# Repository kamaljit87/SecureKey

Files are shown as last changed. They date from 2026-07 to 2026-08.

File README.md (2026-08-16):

<div align="center">

# 🔐 SecureKey

### An offline, hardware password manager that **types your passwords for you** — over USB‑C *and* Bluetooth.

Built on a 1.8" AMOLED touchscreen ESP32‑S3. No cloud. No app account. Your vault never leaves the device.









</div>

> **SecureKey** is a DIY [hardware password manager](https://en.wikipedia.org/wiki/Password_manager) — a tiny touchscreen "keyboard emulator." Pick an entry, tap a field, and the device types it into whatever it's plugged into (PC over USB‑C) or paired with (phone/laptop over Bluetooth). Because it presents itself as a **HID keyboard**, it works on any OS with zero drivers, zero browser extensions, and zero software installed. The secrets live in flash on the device, behind a PIN — never synced, never uploaded.

<p align="center">
  SecureKey on-device screens — Lock, Home, and password Detail
  <br><sub><i>Illustrative renders of the on‑device UI · 368 × 448 AMOLED</i></sub>
</p>

---

## 🔑 What it does, in one picture

```mermaid
flowchart LR
    V["Your vault<br/>lives on the device"] --> P["Pick an entry,<br/>tap a field"]
    P --> Q{"Connected<br/>how?"}
    Q -->|USB-C cable| U["Types into your<br/>PC / Mac as a keyboard"]
    Q -->|Bluetooth| W["Types into your phone<br/>or laptop, wirelessly"]
```

To the computer it just looks like someone typing — **no app, no browser extension, no account.**

---

## 🆚 How it compares

| | **SecureKey** | Cloud manager | Browser autofill |
|---|:---:|:---:|:---:|
| Where the secrets live | 🔒 on the device | ☁️ a company server | 💻 your browser profile |
| Needs an account | ❌ | ✅ | ✅ |
| Needs software on the host | ❌ | ✅ | ✅ |
| Works on any device, no install | ✅ | ❌ | ❌ |
| Usable fully offline | ✅ | ❌ | ❌ |
| Open hardware + firmware | ✅ | ❌ | ❌ |

---

## ✨ Features

| | Feature | What it does |
|---|---|---|
| ⌨️ | **Dual‑transport typing** | Types passwords as real keystrokes over **USB‑C HID** *and* **Bluetooth LE HID** — both can be live at once. |
| 🔢 | **PIN lock + brute‑force backoff** | 4‑digit unlock with escalating lockout (30 s → 60 s → 2 m → 5 m) that survives reboots. |
| 📶 | **On‑device BLE pairing gate** | A connecting phone is *blocked* until you tap **Accept** on the device. Reject, or **Block for 5 min**. Shows the peer's Bluetooth address. |
| 🗂️ | **30,000‑entry vault** | Fixed‑size binary records on FFat, with a PSRAM index so the list scrolls instantly. |
| 🔎 | **Instant search & favorites** | Live filtering with an on‑screen keyboard, plus a ❤️ favorites view. |
| 🌐 | **Wi‑Fi import/export portal** | Spin up a captive‑portal web app to bulk‑import a CSV (Chrome/Google export auto‑detected) or export your vault — code‑protected. |
| ✋ | **Drag‑to‑rearrange home** | Long‑press a home tile and drag it, just like arranging apps on a phone. Order persists. |
| 🅰️ | **Android `@` fix** | One‑tap toggle that fixes the classic US↔UK keycode swap (where `@` types as `"`) on Android hosts. |
| 🔒 | **Auto‑lock, sleep, factory reset** | Idle auto‑lock, double‑tap‑to‑sleep, PIN‑gated factory wipe, change‑PIN flow. |
| 🎨 | **Hand‑drawn AMOLED UI** | A custom, double‑buffered graphics UI (no LVGL) tuned for pure‑black AMOLED — glow effects, color avatars, pill toggles. |

---

## 🧭 Getting around

```mermaid
flowchart LR
    L["Lock"] --> P["PIN"]
    P --> H["Home"]
    H --> List["Passwords"]
    H --> Add["Add new"]
    H --> Fav["Favorites"]
    H --> Set["Settings"]
    List --> D["Detail<br/>tap a field → it types"]
```

> The renders at the top show the Lock, Home, and Detail screens. Real device photos are welcome — drop them in `docs/img/` and link them here.

---

## 🧰 Hardware

| Part | Detail |
|---|---|
| **Board** | [MaTouch ESP32‑S3 1.8" AMOLED (FT3168)](https://www.makerfabs.com/) — ESP32‑S3 R8 |
| **MCU** | ESP32‑S3, dual‑core, **8 MB OPI PSRAM**, **16 MB flash** |
| **Display** | 1.8" AMOLED, **368 × 448**, SH8601 controller over **QSPI** |
| **Touch** | FT3168 capacitive, I²C |
| **LED** | WS2812 (single RGB pixel) — status feedback |
| **USB** | USB‑C, native ESP32‑S3 (USB‑OTG / TinyUSB) |
| **Power** | USB‑C, optional 3.7 V LiPo |

---

## 🚀 Quick start

### 1. Install the toolchain (use these **exact** versions)

| Tool | Version | Where |
|---|---|---|
| Arduino IDE | 2.3.x | [arduino.cc](https://www.arduino.cc/en/software) |
| `esp32` boards core | **2.0.16** | Boards Manager — do **not** use 3.x |
| GFX Library for Arduino | **1.3.7** | Library Manager |
| NimBLE‑Arduino | **1.4.3** | Library Manager — do **not** use 2.x |
| ESP32 BLE Keyboard (T‑vK) | latest | Library Manager *(+ 2 small patches, below)* |
| Adafruit NeoPixel | latest | Library Manager |

Add this Boards Manager URL first (**File → Preferences → Additional URLs**):
```
https://raw.githubusercontent.com/espressif/arduino-esp32/gh-pages/package_esp32_index.json
```

### 2. Patch the BLE keyboard library (two one‑line edits)

The stock **ESP32 BLE Keyboard** ships with the heavyweight Bluedroid backend and MITM‑required pairing, which break USB+BLE coexistence and silent‑fail on Windows/Android. In your `…/Arduino/libraries/ESP32_BLE_Keyboard/` copy:

```diff
// BleKeyboard.h
- // #define USE_NIMBLE
+ #define USE_NIMBLE          // half the RAM; coexists with native USB HID

// BleKeyboard.cpp  (inside begin(), the USE_NIMBLE branch)
- BLEDevice::setSecurityAuth(true, true, true);
+ BLEDevice::setSecurityAuth(true, false, true);   // SC "Just Works" pairing
```

### 3. Arduino IDE board settings (Tools menu)

```
Board:              ESP32S3 Dev Module
PSRAM:              OPI PSRAM                       ← REQUIRED (canvas lives here)
Flash Size:         16MB (128Mb)
Partition Scheme:   16M Flash (3MB APP/9.9MB FATFS)
USB CDC On Boot:    Enabled
USB Mode:           USB-OTG (TinyUSB)               ← REQUIRED for USB HID typing
Upload Mode:        UART0 / Hardware CDC
CPU Frequency:      240MHz
Flash Mode:         QIO 80MHz
```

### 4. Flash

Open `06_PasswordManager/06_PasswordManager.ino` and Upload. First boot seeds a few demo entries so you can see the UI immediately.

<details>
<summary><b>Prefer the command line? (arduino-cli)</b></summary>

```bash
arduino-cli compile \
  --fqbn "esp32:esp32:esp32s3:PartitionScheme=app3M_fat9M_16MB,PSRAM=opi,FlashSize=16M,USBMode=default,CDCOnBoot=cdc" \
  06_PasswordManager
```
(`USBMode=default` is USB‑OTG/TinyUSB.) This is exactly what the [CI workflow](.github/workflows/build.yml) runs on every push.
</details>

### 5. First unlock

There's no default PIN. First boot walks you through choosing your own PIN
(4/6/8 digits — 6+ recommended), which is used to derive the key that
protects your vault and is never itself stored on the device. See
[docs/SECURITY.md](docs/SECURITY.md) for how this works.

---

## 🕹️ Using it

1. **Tap to wake → enter PIN → Home.**
2. Open **Passwords**, tap an entry.
3. On the detail screen, **tap any field** (Title / User / Pass / URL / Note) — SecureKey **types it** into the focused field on your computer/phone.
4. Password is masked; first tap reveals it, second tap types it.
5. **Bottom bar:** `EDIT` · ❤️ · `DELETE`.

**To type over USB:** plug the USB‑C into a PC data port → tap a field. **To type over Bluetooth:** Settings → turn on Bluetooth → pair "SecureKey" from your phone → unlock the device → tap **Accept** on the request → tap a field.

> 💡 If `@` comes out as `"` on Android, enable **Settings → Android @ Fix**.

---

## 🧠 Feature concepts (how it actually works)

A short tour of the interesting engineering. For the full deep dive see **[docs/ARCHITECTURE.md](docs/ARCHITECTURE.md)**.

### ⌨️ HID — "the device *is* a keyboard"
Both USB and Bluetooth expose a standard **[HID keyboard](https://en.wikipedia.org/wiki/USB_human_interface_device_class)**. The OS sees a normal keyboard, so typing works everywhere with no software. The firmware sends **scancodes**, and the host applies its own keyboard layout — which is why the Android `@`→`"` swap exists (see below).

### 🔀 Dual transport on a dual‑core chip
USB HID uses **TinyUSB**; Bluetooth HID uses **NimBLE** (chosen over Bluedroid because it uses ~half the RAM and coexists with native USB). The ESP32‑S3 has two cores and NimBLE runs its own radio task, so **both transports can be live simultaneously** — `typeViaHID()` sends to *every* ready transport instead of picking one.

### 📶 The Bluetooth pairing gate
A BLE *central* (your phone) can connect to the device any time, but SecureKey **types nothing until you physically accept it** on‑screen — and the prompt only appears *after* you've entered your PIN. You can **Accept**, **Reject** (snoozes the prompt so an auto‑reconnecting phone doesn't nag), or **Block 5 min** (drops the radio). The prompt shows the peer's Bluetooth MAC. *(A BLE central doesn't transmit a friendly name to a keyboard, so the address is what's identifiable.)*

```mermaid
sequenceDiagram
    participant Phone
    participant SecureKey
    participant You
    Phone->>SecureKey: BLE connect
    Note over SecureKey: typing stays BLOCKED
    SecureKey->>You: "A device wants to connect" (after PIN unlock)
    You-->>SecureKey: Accept / Reject / Block 5 min
    Note over SecureKey: only Accept unlocks typing
    SecureKey->>Phone: now types your password
```

### 🔑 The Android `@`→`"` fix
HID sends key *positions*, not characters. On a host set to a UK/Android layout, `Shift+2` is `"` (not `@`), and `@` lives on `Shift+'`. The **Android @ Fix** toggle swaps those two keycodes on the BLE path so symbols land correctly — the classic US↔UK keyboard difference, solved in firmware.

### 🗂️ Storage: flat binary + PSRAM index
The vault is **fixed‑size 256‑byte records** appended to a single FFat file (`db.bin`). At boot a compact 64‑byte **index** per entry is loaded into **PSRAM**, so searching, sorting, and scrolling never touch flash. Deletes are tombstoned; edits rewrite in place. This scales to **30,000 entries** (≈1.9 MB index in PSRAM, ≈7.3 MB on the 9 MB FAT partition).

### 🛡️ PIN lockout backoff
Wrong PINs trigger an **escalating, persisted** lockout (30 s → 60 s → 2 m → 5 m). The fail count lives in NVS, so power‑cycling doesn't reset the penalty — a brute‑force attacker can't just yank power to retry instantly.

### 🌐 Wi‑Fi import/export portal
Bulk data entry on a touchscreen is painful, so Settings can launch a **SoftAP + captive‑portal web app**. You join its Wi‑Fi, open the page, enter a one‑time code, and paste a CSV (Chrome/Google password exports auto‑detected) or export your vault. Every entry requires title + username + password — enforced both in the browser and server‑side.

### ✋ Drag‑to‑rearrange home (touch state machine)
The FT3168 driver feeds a tap/drag/swipe state machine. A **long‑press** on a home tile lifts it; it follows your finger; on release it drops into the nearest slot and the others shuffle to make room. The arrangement is saved to NVS and validated as a permutation on load.

### 🎨 Rendering on pure‑black AMOLED
The UI is hand‑drawn into a **double‑buffered canvas** in PSRAM and flushed over QSPI — no LVGL, no flicker. Because AMOLED black is truly off, the theme leans into **glow halos** (banded radial gradients), color **letter‑avatars**, and a blue/red accent system on black.

---

## 🗺️ Architecture

```
06_PasswordManager/
├── 06_PasswordManager.ino   Main: setup/loop, nav stack, HID dispatch, BLE gate, auto-lock
├── theme.h                  Palette, layout constants, PassRecord + ListItem structs, capacity
├── pin_config.h             Board pin map (display, touch, LED, USB)
│
├── hid_usb.cpp              USB-HID keyboard (TinyUSB)            ← isolated translation unit
├── hid_ble.cpp              BLE-HID keyboard (NimBLE) + @ fix     ← isolated translation unit
│
├── storage.ino             FFat binary DB: append/load/delete/update/seed
├── touch_input.ino         FT3168 reader + tap/drag/swipe/long-press state machine
├── gfx_lib.ino             Drawing helpers: text, icons, glow, avatars, status/nav bars
├── keyboard.ino            On-screen keyboard (search + add/edit)
│
├── screen_lock.ino         Branded lock screen
├── screen_pin.ino          4-digit keypad + lockout countdown
├── screen_home.ino         Home grid + drag-to-reorder
├── screen_list.ino         Virtual-scroll list + inline search + favorites
├── screen_detail.ino       Entry detail + Edit/Fav/Delete + tap-to-type
├── screen_add.ino          Multi-step add / edit form
├── screen_settings.ino     Settings, HID test, About, factory reset
├── screen_chgpin.ino       Change-PIN flow
├── screen_wifi.ino         Wi-Fi import status screen
├── wifi_portal.ino         SoftAP + HTTP server (import/export)
└── portal_html.h           The captive-portal single-page web app
```

> ⚠️ **USB & BLE keyboard libraries each `#define KEY_*` macros**, so they cannot share a translation unit. That's why `hid_usb.cpp` and `hid_ble.cpp` are separate `.cpp` files exposing a tiny `extern "C"` surface to the `.ino` code.

---

## 🔐 Security model & honest limitations

Full write‑up (threat model, cryptographic design, migration, and the exact
ESP32‑S3 Flash Encryption / Secure Boot production steps) lives in
**[docs/SECURITY.md](docs/SECURITY.md)**. Summary:

**What it does today**
- Vault is **offline**, PIN‑gated, and **encrypted at rest**: every record is
  AES‑256‑GCM with its own random nonce, under a random 256‑bit master key
  that is itself wrapped by a PBKDF2‑HMAC‑SHA256‑derived key — never the PIN
  directly, and the PIN is never stored anywhere, in any form.
- The screen locks on idle and on the physical button; locking wipes the
  master key from RAM, not just the display.
- Brute‑force PIN backoff persists across reboots, on top of the real KDF
  cost every guess pays regardless of that counter.
- Bluetooth typing requires **explicit on‑device approval** per connection.
- Factory reset destroys the old cryptographic identity entirely (new random
  master key, new salt) — it can't be used to bypass the PIN and recover an
  old vault.
- An existing plaintext vault (pre‑encryption firmware) migrates
  automatically on first boot of this firmware, with a verify‑before‑delete
  step so the old data is never lost to a failed migration.

**What it does *not* do** (see SECURITY.md § Security limitations for the
full list)
- Optional **ESP32‑S3 Flash Encryption + Secure Boot v2** (whole‑flash /
  firmware‑signing hardening on top of the above) is documented but **not
  auto‑enabled** — it's a manual, explicit, one‑way eFuse step you run
  yourself when you're ready for a production device, never something the
  build or firmware does for you.
- A compromised or *currently unlocked* device, sophisticated hardware
  attacks (glitching, side‑channel), and firmware bugs elsewhere in the
  codebase are outside what this (or any) microcontroller password manager
  can fully defend against.

Treat this as a **serious DIY / hobbyist‑grade hardened project**, not a
certified security product — see the roadmap.

---

## 🛣️ Roadmap

- [x] Touch UI, vault, USB + BLE HID, Wi‑Fi import, drag‑reorder
- [x] **AES‑256‑GCM encrypted vault** (random master key, PBKDF2‑derived PIN wrapping — see [docs/SECURITY.md](docs/SECURITY.md))
- [ ] **Flash Encryption + Secure Boot v2 enabled by default in a documented production build** (the steps are written up in SECURITY.md today; still a manual per‑device process, not yet a one‑command flow)
- [ ] **TOTP / 2FA** code generator (HMAC‑SHA1)
- [ ] **FIDO2 / WebAuthn** passkey (ECC P‑256)
- [ ] Custom PCB + 3D‑printed enclosure

---

## 🤝 Contributing

Contributions, bug reports, and hardware ports are welcome — see **[CONTRIBUTING.md](CONTRIBUTING.md)**. The CI compiles the firmware on every push, so make sure your branch builds green.

## 📜 License

[MIT](LICENSE) © Shubh Jaiswal.

## 🙌 Credits

- [Makerfabs](https://www.makerfabs.com/) — MaTouch ESP32‑S3 AMOLED hardware
- [moononournation/Arduino_GFX](https://github.com/moononournation/Arduino_GFX) — display driver
- [h2zero/NimBLE‑Arduino](https://github.com/h2zero/NimBLE-Arduino) — lightweight BLE stack
- [T‑vK/ESP32‑BLE‑Keyboard](https://github.com/T-vK/ESP32-BLE-Keyboard) — BLE HID keyboard
- [adafruit/Adafruit_NeoPixel](https://github.com/adafruit/Adafruit_NeoPixel) — WS2812 LED

<div align="center">

**If this project helped you, drop a ⭐ — it genuinely helps.**

</div>

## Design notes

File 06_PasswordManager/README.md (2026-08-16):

# SecureKey — firmware

This folder is the **SecureKey** password‑manager firmware (Arduino sketch).
Open `06_PasswordManager.ino` in the Arduino IDE and Upload.

👉 Full documentation, build settings, and feature explanations are in the
[**project README**](../README.md) and [**docs/ARCHITECTURE.md**](../docs/ARCHITECTURE.md).

## TL;DR build settings

```
Board:            ESP32S3 Dev Module
PSRAM:            OPI PSRAM
Partition:        16M Flash (3MB APP/9.9MB FATFS)
USB CDC On Boot:  Enabled
USB Mode:         USB-OTG (TinyUSB)
```

Requires: esp32 core **2.0.16**, NimBLE‑Arduino **1.4.3**, GFX Library for Arduino **1.3.7**,
Adafruit NeoPixel, and the patched ESP32 BLE Keyboard (see the project README).

There is no default PIN. First boot walks you through choosing your own PIN
(4/6/8 digits, 6+ recommended) — it's never stored anywhere, only used to
derive the key that unlocks your vault. See
[docs/SECURITY.md](../docs/SECURITY.md) for the full design.

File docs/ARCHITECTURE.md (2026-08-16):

# SecureKey — Architecture & Feature Concepts

A deep dive into how SecureKey works, for contributors and the curious. For the high‑level pitch and setup, see the [README](../README.md).

---

## 1. The big picture

SecureKey is a single‑threaded Arduino sketch built around a **screen state machine** and a **non‑blocking main loop**. There is no RTOS scheduling in user code — instead `loop()` polls touch at ~60 Hz, runs lightweight per‑screen animation timers, and services background managers (BLE, Wi‑Fi portal, auto‑lock). The two HID stacks (USB via TinyUSB, BLE via NimBLE) run their own tasks under the hood.

```
            ┌────────────────────────── loop() @ ~60 Hz ──────────────────────────┐
            │  pollTouch() ─► tap / drag / swipe / long-press  ─►  onTapXxx()      │
            │  per-screen animation ticks (lock pulse, PIN shake, list inertia)    │
            │  BLE manager (advertise state, connect gate)                         │
            │  Wi-Fi captive portal service                                        │
            │  auto-lock / LED auto-clear / physical button                        │
            └──────────────────────────────────────────────────────────────────────┘
```

---

## 2. Screen state machine & navigation

Every screen is a pair of functions:

```c
void drawXxx();                       // render the whole screen into the canvas
void onTapXxx(int16_t x, int16_t y);  // handle a tap at (x, y)
```

`current` holds the active `Screen` enum. A small **navigation stack** (`navStack[10]`, `navTop`) gives Android‑style back behaviour:

- `pushNav(SCR_X)` — go deeper (also runs per‑screen entry hooks, e.g. `buildList()` for the list, `pinSlideIn()` for the PIN animation).
- `popNav()` — go back one level.
- `popToLock()` — collapse to the lock screen (idle timeout, physical button).

`drawAll()` and `dispatchTap()` are the two switch statements that route to the active screen. **Adding a screen = write the pair, add a `SCR_` enum, register in both switches.**

Rendering is **double‑buffered**: everything is drawn into an `Arduino_Canvas` in PSRAM, then `flushScreen()` (`gfx->flush()`) pushes the whole frame to the AMOLED over QSPI in one shot. No partial draws, no flicker, no tearing.

---

## 3. Touch: from capacitive blob to gesture

`touch_input.ino` reads the FT3168 over I²C (`ftReadTouch()` — register `0x02` for the touch count, `0x03` for the first point) and runs a small state machine in `pollTouch()`:

| Transition | Meaning | Fires |
|---|---|---|
| no‑touch → touch | finger down | records start point + time |
| touch → touch (moved > `DRAG_THRESHOLD`) | it's a drag | `onDrag()` live callback |
| touch held > 500 ms, no move | **long‑press** | `homeLongPress()` (home only) |
| touch → release, was a drag | swipe/scroll end | `onSwipeEnd()` |
| touch → release, was short & still | **tap** | `dispatchTap()` |

This single machine powers list scrolling (with inertia/friction), swipe‑back, the slide‑up PIN entrance, and the home drag‑to‑reorder — all without blocking the loop.

---

## 4. Data model & storage

> 🔐 The vault is **encrypted at rest** (AES‑256‑GCM, per‑record nonces, a
> random master key wrapped by a PBKDF2‑derived, PIN‑based key). This
> section covers the in‑RAM `PassRecord`/`ListItem` shapes the UI code
> works with — for the actual on‑disk format, the key‑derivation design,
> the threat model, and the migration path from the old plaintext format,
> see **[docs/SECURITY.md](SECURITY.md)**.

### Record layout (in‑RAM representation)

The UI/business logic still works with a **fixed‑size 256‑byte** in‑RAM
`PassRecord` — unchanged from before, so screens and features didn't need to
be rewritten:

```c
struct __attribute__((packed)) PassRecord {  // 256 bytes, RAM-side shape
  uint16_t id;            // stable identifier
  uint8_t  deleted;       // tombstone flag
  char     folder[24];    // reused as the URL/subtitle
  char     title[40];
  char     username[64];
  char     password[48];
  char     url[60];
  char     note[16];
  uint8_t  favorite;      // heart flag
};
```

What changed is what happens *between* a `PassRecord` and the file: every
write goes through `dbEncryptRecord()` (AES‑256‑GCM, fresh random nonce every
time), and every read that needs the full record goes through
`dbDecryptRecord()`. Only the *current* screen's record is ever decrypted
into RAM at a time — see SECURITY.md's "reduced plaintext residence time".

### Why a separate PSRAM index?

Re‑reading flash to render a scrolling list would be slow, wear the flash,
**and** require decrypting the whole vault on every scroll frame. Instead,
at boot (once unlocked) `dbLoadIndex()` builds a compact **64‑byte
`ListItem`** per entry (id, favorite, title, subtitle) in **PSRAM** — the
only fields it needs are the ones already treated as UI labels rather than
secrets (see SECURITY.md for why title/folder are the one exception kept in
plaintext in RAM):

```c
struct __attribute__((packed)) ListItem {  // 64 bytes
  uint16_t id;
  uint8_t  favorite;
  char     folder[21];
  char     title[40];
};
```

Searching, sorting (`qsort` by title), and the virtual‑scroll list all operate on this in‑RAM index — flash is only touched to open a single full (encrypted) record (`dbLoadRecord()`, which decrypts it) or to write (`dbAppend`/`dbUpdate`/`dbDelete`, which re‑encrypt).

### Operations

| Op | Strategy |
|---|---|
| Add | encrypt + append one record (`dbAppend`) |
| Edit | rewrite file transactionally, replace matching `id`'s ciphertext in place |
| Delete | rewrite file with `deleted = 1` (tombstone) — record stays encrypted, just flagged |
| Toggle favorite | decrypt, flip flag, re‑encrypt with a fresh nonce, reload index |

All of the above share one transactional rewrite path (`dbRewriteTransacted()`
in `storage.ino`) that verifies a complete new file before ever replacing
the old one — see SECURITY.md § Crash safety.

### Capacity

`MAX_PASSWORDS = 30000`. That's ≈ **1.9 MB** of index in the 8 MB OPI PSRAM, plus a 2‑byte‑per‑entry sort array, and the on‑disk encrypted record size (id/flags + 12‑byte nonce + 16‑byte auth tag + ciphertext payload) comfortably fits the 9 MB FAT partition at the same ~30,000‑entry cap. `uint16_t` ids/counters comfortably cover 30 000 entries.

---

## 5. HID: the device pretends to be a keyboard

Both transports advertise a standard **HID keyboard**, so the host needs no driver or software. The firmware sends USB HID **usage codes** (scancodes); the **host** maps them to characters using *its* keyboard layout.

### Why two translation units?

`USBHIDKeyboard.h` (TinyUSB) and `BleKeyboard.h` (NimBLE) both `#define KEY_TAB`, `KEY_RETURN`, etc. and both declare a `KeyReport` — they **cannot** be `#include`d in the same `.cpp`. So:

- `hid_usb.cpp` owns the USB keyboard.
- `hid_ble.cpp` owns the BLE keyboard.
- Each exposes a tiny `extern "C"` surface (`hidUsbPrint`, `hidBlePrint`, …). The `.ino` code never sees the library headers.

### Dual‑transport dispatch

`typeViaHID()` doesn't pick one transport — it sends to **every** ready one:

```
if (BLE enabled && connected && user-accepted)  hidBlePrint(s);
if (USB enabled && host has enumerated us)       hidUsbPrint(s);
```

NimBLE runs its radio work on its own task and coexists with native USB on the dual‑core S3, so "BLE on" never disables USB and vice‑versa.

### USB mount detection

USB typing only fires once `tud_mounted()` (TinyUSB) reports the host has enumerated the keyboard — that's why plugging into a *charger* (no data) won't type, and why the firmware waits briefly after `USB.begin()` for Windows to enumerate.

---

## 6. Bluetooth: pairing gate & the stuck‑key fix

### The pairing gate

A BLE *central* (phone/PC) can connect to our peripheral at any time, but SecureKey **types nothing until the user accepts on‑device** — and only once unlocked. The `loop()` BLE manager detects a new connection and, if unlocked + screen on + not in a block window, calls `bleConnectGate()`:

- **Accept** → `bleAuthorized = true`; typing allowed.
- **Reject** → keep the link up (a paired phone auto‑reconnects instantly, which would loop the prompt) but stay unauthorized, and **snooze** the prompt 20 s.
- **Block 5 min** → drop the radio entirely for 5 minutes.

The prompt shows the peer's Bluetooth address (`hidBlePeerAddr()` → `NimBLEServer::getPeerIDInfo().getAddress()`). A central doesn't transmit a friendly name to a keyboard, so the MAC is what's identifiable.

### Live on/off without reboot

The patched `BleKeyboard::end()` is a no‑op and calling `begin()` twice duplicates GATT services, so `hid_ble.cpp` calls `kb.begin()` **exactly once per boot** (`everStarted`). Turning BLE on/off afterward uses raw NimBLE: `getAdvertising()->start()/stop()` plus `server->disconnect(peer)`.

### Just‑Works pairing

The library default `setSecurityAuth(true, true, true)` demands MITM protection, but this device has no passkey entry/display — so Windows and some Androids paired but never encrypted (connected, never typed). Patched to `(true, false, false)` = **bonded "Just Works"** pairing, the correct profile for a display‑less keyboard.

### The "…gmmmmm" stuck‑key bug

A HID keystroke is a **key‑down report** followed by a **key‑up report**. `kb.write()` sends both back‑to‑back, so over BLE they can land in the *same* connection event and the host misses the release → it auto‑repeats the last key forever. The fix in `bleType()`:

```
press(key)  →  hold ~32 ms (spans a connection interval)  →  releaseAll()  →  small gap
```

Key‑down and key‑up now land in **different** connection events. We also request a tighter connection interval (`updateConnParams`) so typing is prompt, and `releaseAll()` at the start/end guarantees nothing is left held.

### The Android `@`→`"` fix

HID sends key *positions*. On a UK/Android layout, `Shift+2` is `"` and `@` lives on `Shift+'`. The **Android @ Fix** toggle makes `bleType()` send `@` as `Shift+apostrophe` (usage `0x34`) and `"` as `Shift+2` (usage `0x1F`), which produce the right glyphs on those hosts — the classic US↔UK swap, fixed in firmware. (Only enable it for Android; on a US host it would invert them.)

---

## 7. Security: PIN, lockout, auto‑lock

> 🔐 Full detail — threat model, cryptographic design, eFuse/Flash
> Encryption/Secure Boot production steps, and stated limitations — lives in
> **[docs/SECURITY.md](SECURITY.md)**. Summary:

- **PIN** is never stored, in any form. It's checked by deriving a key
  (PBKDF2‑HMAC‑SHA256) and attempting to unwrap the AES‑256‑GCM‑wrapped
  master key with it — a wrong PIN fails that unwrap (GCM authentication),
  there is no separate stored PIN/hash to compare against. Correct entry
  jumps straight to Home.
- **Brute‑force backoff** (`pinRegisterFail`): the 3rd wrong attempt locks the keypad 30 s, then 60 s, 2 m, 5 m. The cumulative fail count is **persisted in NVS**, so a power‑cycle doesn't reset the penalty (millis() resets, but the next wrong attempt jumps straight back to a long wait). This sits on top of, not instead of, the PBKDF2 cost every guess pays regardless.
- **Auto‑lock** after configurable idle, and the physical button → instant lock. Locking wipes the master key from RAM (`vaultLock()`), not just switching screens.
- **Factory reset** is **PIN‑gated**, then a second confirm, then wipes `db.bin` **and** the crypto‑material NVS namespace (salt, wrapped master key) **and** BLE bonds, then reboots into first‑time setup with an entirely new random master key — a reset can't be used to silently recover the old vault.

> The vault **is encrypted at rest**: AES‑256‑GCM per record, random master
> key wrapped by a PIN‑derived key (never the PIN itself, never a
> hard‑coded key). Optional ESP32‑S3 Flash Encryption + Secure Boot v2 (a
> manual, documented, non‑automated production step — see SECURITY.md)
> harden the firmware/flash‑image layer on top of this. Treat SecureKey as
> a serious hobbyist‑grade hardening project — see SECURITY.md's own
> "Security limitations" section for what this does *not* protect against.

---

## 8. Wi‑Fi import/export portal

Typing many entries on a touchscreen is painful, so Settings can start a **SoftAP + HTTP server** (`wifi_portal.ino`) serving a single‑page web app (`portal_html.h`):

- Join the device's Wi‑Fi, open the page, enter a one‑time **access code**.
- **Import**: paste lines or a CSV — Chrome/Google password exports are auto‑detected (`title,url,username,password` order).
- **Export**: download the vault as CSV.
- Every entry requires **title + username + password** — validated in the browser *and* server‑side in `portalSaveEntry()` (so even bulk lines can't create half‑empty records).

The portal is torn down automatically when you navigate away from the Wi‑Fi screen.

---

## 9. Home drag‑to‑reorder

`homeOrder[slot] = item` maps grid positions to menu items. A long‑press lifts a tile (`homeLongPress`), it follows the finger (`homeDrag`), and on release it drops into the nearest slot, shuffling the rest (`homeRelease`). The order is saved to NVS (`horder`) and **validated as a permutation** on load, so a corrupt value can never brick the home screen. Tap **DONE** to leave arrange mode (also forced on lock).

---

## 10. Rendering style on AMOLED

`gfx_lib.ino` is the drawing toolkit: text helpers, icons, status/nav bars, and a small **color engine** (`lerp565` blend, `glowCircle` banded radial gradient, letter‑avatar palette). Because AMOLED black is genuinely *off*, the theme uses black backgrounds with **glow halos** and a blue/red accent system, color **letter‑avatars** for entries, and iOS‑style pill toggles — all hand‑drawn, no LVGL, into the double‑buffered canvas.

---

## File map

| File | Responsibility |
|---|---|
| `06_PasswordManager.ino` | setup/loop, nav stack, HID dispatch, BLE gate, PIN lockout, settings persistence |
| `theme.h` | palette, layout constants, `PassRecord`/`ListItem`, capacity, `UserSettings`, `SECUREKEY_DEBUG`/`SK_LOG` |
| `pin_config.h` | board pin map |
| `crypto_core.h` / `.cpp` | mbedTLS wrappers: PBKDF2, AES‑256‑GCM, HW RNG, secure‑wipe — **see [SECURITY.md](SECURITY.md)** |
| `shared_types.h` | cross‑file structs/typedefs (on‑disk DB layout, vault crypto params, legacy‑migration record, password‑generator options) |
| `vault_crypto.ino` | PIN → KEK → master‑key lifecycle (provision/unlock/rewrap/lock/erase) |
| `db_migrate.ino` | one‑time legacy plaintext → encrypted DB migration (streamed, verify‑before‑delete) |
| `pwgen.ino` | cryptographically‑secure password generator (HW RNG, rejection sampling) |
| `hid_usb.cpp` / `hid_ble.cpp` | the two isolated HID keyboards |
| `storage.ino` | encrypted FFat DB (AES‑256‑GCM per record) + demo‑mode‑only seed data |
| `touch_input.ino` | FT3168 reader + gesture state machine |
| `gfx_lib.ino` | drawing helpers + color engine |
| `keyboard.ino` | on‑screen keyboard |
| `screen_*.ino` | one file per screen (`draw` + `onTap`), including `screen_setup_pin.ino` (first‑boot/reset PIN setup) and `screen_migrate.ino` (migration confirm/progress) |
| `wifi_portal.ino` + `portal_html.h` | import/export web app — now reads/writes exclusively through the encrypted‑DB API, never raw FFat |
| `partitions_securekey_prod.csv` | production partition table with an `nvs_keys` slot (for NVS Encryption) — see SECURITY.md |

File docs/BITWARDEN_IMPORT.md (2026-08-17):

# SecureKey — Bitwarden Import

This document describes the Bitwarden vault-import feature: how to export
from Bitwarden, how to start an import on-device, exactly what data is
supported and unsupported, how the import is secured, what happens to the
temporary data involved, and how duplicates are handled.

Imported credentials are written through the **exact same**
`dbEncryptRecord()` / AES-256-GCM path every on-device-created password
goes through (see [`docs/SECURITY.md`](SECURITY.md) for the underlying
vault architecture, which this feature reuses unchanged). There is no
separate "import database," no new master key, and no weakening of the
existing vault encryption.

---

## 1. Exporting from Bitwarden

1. In the Bitwarden web vault or desktop app: **Settings → Export Vault**.
2. **File Format: `.json`** — select the plain `.json` export, **not** the
   "Password Protected" / encrypted `.json` variant. SecureKey does not
   implement Bitwarden's encrypted-export format (see
   [§5, Encrypted exports](#5-encrypted-exports-not-supported) below).
3. Confirm your Bitwarden master password when prompted.
4. Save the resulting `.json` file somewhere you control (your computer or
   phone's own storage) — **do not** upload it to any third-party website.
   Bitwarden's own docs are authoritative for exact menu wording, since
   this project doesn't control that UI.

## 2. Starting an import on SecureKey

1. Unlock the device with your PIN.
2. **Settings → Import** → **Bitwarden Import**.
3. Read and accept the on-device warning:

   > *This export contains your passwords in plaintext. Only import it
   > over a trusted connection. SecureKey will encrypt the vault after
   > import.*

   This is not a formality — the file genuinely contains every password
   in cleartext until SecureKey encrypts it. Tapping **CONTINUE** is a
   deliberate acknowledgment, not a rubber stamp.
4. The device starts a temporary WiFi hotspot and shows an SSID, a
   randomly-generated WPA2 password, and a randomly-generated 6-digit code
   — all fresh for this session, all shown **only on the device screen**.
5. On your computer or phone: join that WiFi network, open a browser to
   the device's address, enter the 6-digit code, choose your exported
   `.json` file, and tap **Upload**.
6. Once the upload finishes, the device shows a **preview**: counts of
   logins, secure notes, and folders found, plus how many items are
   unsupported or look like duplicates — never any password, username, or
   item name content (see [§7](#7-what-the-preview-shows-and-does-not-show)).
7. Tap **IMPORT** to commit, or **CANCEL** to discard everything with no
   changes to your vault.
8. On success: a summary of how many entries were added, and the WiFi
   hotspot shuts down automatically.

## 3. How the import is secured

| Concern | Behavior |
|---|---|
| Portal availability | Disabled by default. Only reachable via Settings → Import → Bitwarden, which requires the device to already be **unlocked** (PIN-authenticated) |
| Session credentials | A fresh random WPA2 password (8 chars) and 6-digit access code are generated for every session (`ckRandomBytes()` — the ESP32-S3 hardware RNG, the same source used for every other secret in this project), shown only on the device's own screen, never logged |
| Route isolation | Import-mode sessions register a **restricted** route set — no `/save`, `/list`, `/edit`, `/delete`, `/export`. An import session's web page has no path to browse or export your *existing* vault, even with the correct code |
| Authorization | Every state-changing request (including the upload itself) requires the session's 6-digit code, checked against `vaultUnlocked` on every request — an idle timeout or lock mid-transfer fails the request closed |
| Auto-shutdown | The portal stops automatically on: import complete, explicit cancel, 3 minutes of no requests, a 10-minute hard session cap regardless of activity, or the device locking for any reason (auto-lock, side-button sleep) |
| Transport | WPA2-encrypted WiFi, single-client SoftAP with no internet uplink — the same isolated-network model the general WiFi manager already uses |
| Encryption at rest | The uploaded data is parsed incrementally and never itself written to flash — see [§8](#8-temporary-data-handling) for exactly what temporary state does exist |
| Atomicity | The vault is only ever replaced by a **fully built and verified** new file — see [§9](#9-how-the-commit-is-verified-before-anything-is-replaced) |

## 4. What's supported

| Bitwarden field | Maps to | Notes |
|---|---|---|
| `name` | title | |
| `login.username` | username | |
| `login.password` | password | Never truncated or dropped |
| `login.uris[0].uri` | url | The **first/primary** URI |
| `login.uris[1+].uri` | note (`[URL2] ...` line) | Additional URIs are preserved, not discarded — but see the truncation note below |
| `folderId` | folder | Resolved through a real folder table (see [§10](#10-duplicate-handling)) — folders import as first-class SecureKey folders, not text labels |
| `notes` | note | |
| `login.totp` | note (`[TOTP] ...` line) | Never shown in the import preview. See the truncation note below |
| custom fields (`fields[]`) | note (`[Custom] name: value` lines) | Never shown in the import preview |
| item type `1` (Login) | a SecureKey password entry | |
| item type `2` (Secure Note) | a SecureKey entry with no username/password | |

### The note-field truncation limitation

**Read this before relying on TOTP or custom fields surviving intact.**
SecureKey's encrypted `note` field is intentionally small (16 bytes) —
unchanged by this feature, since growing it would mean changing the
encrypted payload's on-disk layout for every existing vault. Extra URIs,
TOTP secrets, and custom fields are all folded into that same small field
alongside your real notes text. In practice: **if an item also has real
notes text, anything appended after it will very likely be cut off** after
about 15 characters total. The password itself is never affected — this
limitation is specific to the note field only.

If TOTP or a custom field's exact value matters to you, open that entry on
the device after import and check its note field directly — don't assume
it made it through fully intact. Keeping Bitwarden notes short before
exporting reduces how much gets cut off.

## 5. Encrypted exports (not supported)

Bitwarden also offers a "Password Protected" encrypted `.json` export.
**SecureKey does not implement Bitwarden's encryption/decryption** — this
project never invents or assumes a third-party crypto scheme from
documentation alone, and doing so incorrectly would be worse than not
supporting it. Use the plain (unencrypted) `.json` export, protected instead
by the on-device warning and the WiFi session's own security properties
described above.

An export whose top-level `"encrypted"` field is `true` is detected and
rejected cleanly by the parser — the import fails immediately with a clear
message, before anything is written anywhere.

## 6. What's unsupported

| Item type | Behavior |
|---|---|
| Identity (type `3`) | Counted as "unsupported," never imported, never partially imported |
| Card (type `4`) | Same |
| Attachments / attachment metadata | Never downloaded, never executed, never referenced — Bitwarden export JSON only contains attachment *metadata* (not the file content itself), and this importer does not act on it at all |

Unsupported items are always **counted and reported** in the preview and
final summary — never silently dropped without being acknowledged.

## 7. What the preview shows (and does not show)

The preview screen, shown after upload and before you confirm anything,
shows **only**:

- Count of logins found
- Count of secure notes found
- Count of folders found
- Count of unsupported items (with a note about which types)
- Count of likely duplicates

It **never** shows: passwords, PINs, TOTP secrets, card numbers, private
notes content, or even item/entry **names** — the safest reading of "handle
item names carefully" is to not show them at all in this preview.

## 8. Temporary data handling

The **raw Bitwarden JSON file is never written to flash at all** — it only
ever exists as small (~1.4 KB) chunks in memory while the upload is
streaming in, parsed and discarded chunk by chunk.

What *is* written to flash temporarily is an already-parsed, normalized
intermediate form — just the extracted fields (title/username/password/
url/note/folder), one small fixed-size record per accepted item — in a file
called `/bw_staging.bin` (plus a small `/bw_folders_staging.bin` for
folder names). This staging file:

- Exists only between the moment the upload finishes and either a
  successful commit or a cancel/failure.
- Is deleted on **every** exit path: successful import, explicit cancel,
  parse failure, verification failure, or the portal being torn down for
  any reason (lock, timeout, navigating away).
- Is protected only by the same on-device filesystem access model as this
  project's other crash-safety temp files (`/db_tmp.bin`, `/db_migrate.bin`)
  — it is **not** encrypted, because it holds plaintext by necessity for
  the short window it exists. This is a real, documented limitation, not
  an oversight: someone with raw flash access during that narrow window
  could recover it, exactly as they already could recover the encrypted
  vault's contents by brute-forcing the PIN. See `docs/SECURITY.md`'s
  "Security limitations" section for this project's general posture on
  flash-level access.

## 9. How the commit is verified before anything is replaced

Confirming the preview does **not** immediately touch your real vault.
Instead:

1. A brand-new database file is built: every one of your *existing*
   records is copied through unchanged, plus every newly-imported record
   freshly encrypted with the same master key and a fresh random nonce.
2. That new file is then **completely re-read and decrypted, record by
   record** — confirming the total count is right, every pre-existing
   record is untouched, and every new record's fields match what was
   staged.
3. **Only if every single record verifies successfully** does the device
   atomically replace the real vault file with the new one.
4. If verification fails at any point, the new (unverified) file is
   deleted and your existing vault is left completely untouched — the
   device tells you the import failed and your vault is safe, and it
   means that literally.

This mirrors the same verify-before-delete discipline this project already
uses for its plaintext-to-encrypted database upgrade (see
`docs/SECURITY.md`).

## 10. Duplicate handling

An imported login is compared against your **existing** vault by
**title + username + URL together** — not title alone, since many
different accounts share a title like "Email." A match on all three is
treated as a duplicate.

Secure Notes (which have no username/URL) are matched by title only — the
best signal available for that item type.

The default (and only, in this version) policy is **skip**: a duplicate is
never imported and never overwrites an existing entry — it's counted and
reported, nothing more. There is currently no "replace" or "keep both"
option; if you want to intentionally re-import something you've since
edited, delete the old entry on-device first.

Duplicates are checked both against your existing vault and within the
imported file itself (two identical entries in the same export are only
imported once).

## 11. Manual test procedure

This project has no automated test harness (it's Arduino firmware, tested
manually against real hardware — the same convention `docs/SECURITY.md`
uses for its own testing checklist). A small fake fixture lives at
[`06_PasswordManager/test_fixtures/bitwarden_export_sample.json`](../06_PasswordManager/test_fixtures/bitwarden_export_sample.json)
(5 logins with 1 intentional duplicate, 2 secure notes, 2 folders, 1 custom
field, 1 TOTP value, 1 unsupported item — all `*.example.invalid` fake
data; see that file's own `README.md`).

1. **Valid import** — flash firmware, unlock, Settings → Import → Bitwarden
   → accept the warning → join the AP, browse to the device IP, enter the
   code, select `bitwarden_export_sample.json`, upload. Confirm the preview
   shows 4 new logins (5 minus 1 duplicate), 2 secure notes, 2 folders, 1
   unsupported. Confirm the import, then verify all 6 new entries appear in
   the password list under the correct folders, the TOTP-bearing entry's
   note shows a `[TOTP]` prefix (likely truncated), and the custom-field
   entry shows a `[Custom]` line.
2. **Malformed JSON** — truncate the fixture mid-string and upload. Expect
   a clean "Import failed" message on-device; confirm the existing vault is
   unchanged.
3. **Empty vault** — upload `{"encrypted":false,"folders":[],"items":[]}`.
   Preview should show all-zero counts; confirming should complete as a
   no-op with no crash and no phantom records.
4. **Large vault** — generate (off-device, not committed to this repo) a
   fixture with ~1500 fake login items and upload it. Confirm no watchdog
   reset, the progress screen's "N / M" count advances, and the final tally
   matches.
5. **Duplicates** — use the fixture's built-in duplicate ("Example Mail"
   appears twice). Confirm exactly 1 is imported and 1 is reported as a
   duplicate. Re-run the same import a second time — this time all 5 logins
   should be reported as duplicates (proving the check is against the
   *now-updated* vault, not just within one batch).
6. **Missing fields** — craft a login item with no `password` key at all.
   Confirm it imports with an empty password field rather than crashing or
   being silently dropped (an item is not required to have every field to
   be imported — only its *contents* determine what SecureKey actually
   stores).
7. **Unsupported item types** — confirm an Identity (type 3) or Card (type
   4) item is counted as "unsupported" and never appears as a password or
   note entry.
8. **Oversized fields** — craft a variant with a 5,000-character password
   and a 10,000-character notes field. Confirm the imported password is
   exactly 47 characters (not corrupted, not longer) and the device doesn't
   hang or crash while parsing the oversized string.
9. **Cancelled import** — start an upload, reach the preview screen, tap
   CANCEL. Confirm the existing vault is unchanged and a subsequent fresh
   import doesn't show any leftover state from the cancelled one.
10. **Interrupted import (power-cycle mid-transfer)** — start uploading the
    large-vault fixture, power off the device partway through. On reboot,
    confirm the device boots normally, the existing vault (all
    pre-import passwords) is completely intact, and starting a fresh
    import works normally.
11. **Existing vault survives a failed commit** — deliberately force a
    verification failure (a temporary debug-only build hook is the
    practical way to do this, removed before release) and confirm the
    on-device message says the import failed and the vault is safe, then
    spot-check a known pre-existing password still decrypts correctly and
    is unchanged.
12. **Imported passwords work via HID** — after a successful import, open
    a newly-imported entry and type it via USB or BLE HID (same as any
    other entry). Confirm the typed text matches the fixture's known fake
    password exactly.
13. **No plaintext in serial logs** — with `SECUREKEY_DEBUG` on, run a full
    import over a USB-serial-monitored session, capture the log, and
    `grep` it for every fake password/TOTP string from the fixture
    (`Demo-Pass-0001!`, `JBSWY3DPEHPK3PXP`, etc.). Expect zero matches —
    matching `docs/SECURITY.md`'s own grep-based verification approach.
14. **Temporary files are gone after success** — after a successful
    import, confirm `/bw_staging.bin`, `/bw_folders_staging.bin`,
    `/bw_import_new.bin`, and `/bw_folders_new.bin` no longer exist on
    flash.

## 12. Limitations

- **Encrypted Bitwarden exports are not supported** — see [§5](#5-encrypted-exports-not-supported).
- **Notes, TOTP secrets, extra URIs, and custom fields are all subject to
  truncation** into a 16-byte field — see the dedicated note above. The
  password itself is never truncated.
- **No "replace" or "keep both" for duplicates** in this version — matches
  always skip. If you need to intentionally re-import an edited entry,
  delete the old one first.
- **Identity and Card items are not imported** — reported as unsupported,
  never partially converted into a password entry.
- **The parsed-but-not-yet-committed staging file is plaintext on flash**
  for the (short) window between upload and commit/cancel — see
  [§8](#8-temporary-data-handling) for exactly what that means and why it's
  unavoidable without changing the transfer mechanism entirely.
- **Item names are never shown during import**, including in the preview —
  a deliberate, conservative choice; you only see aggregate counts until
  the import is committed and you're looking at your actual, decrypted
  vault.

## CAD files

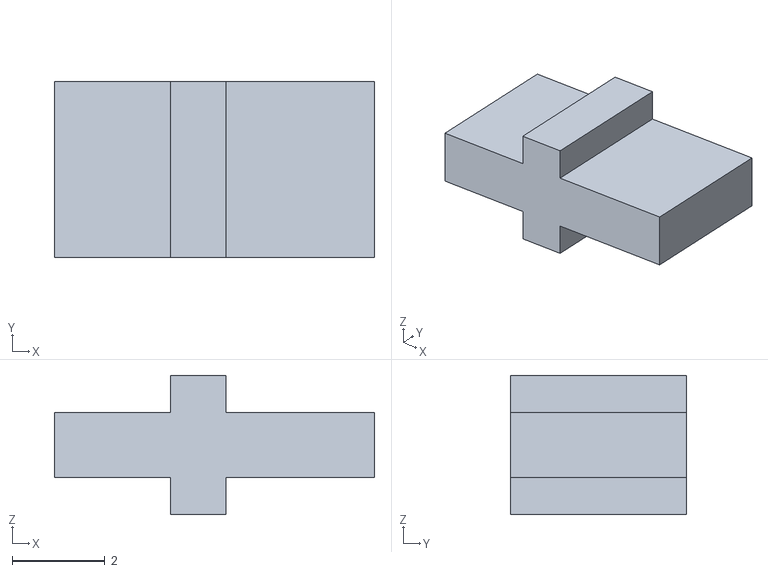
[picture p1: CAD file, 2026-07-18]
3D Print Files /Assem2 - button-1.STL
6.90 x 3.80 x 3.00

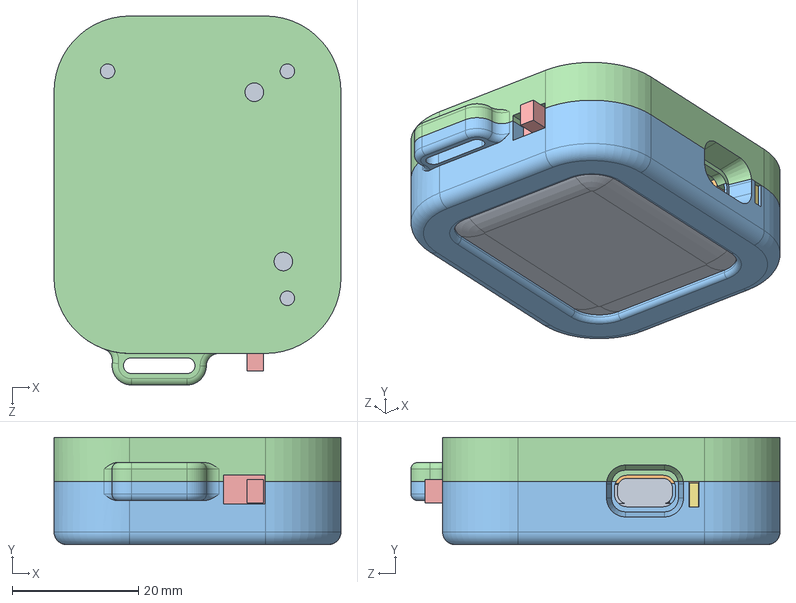
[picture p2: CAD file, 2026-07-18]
3D Print Files /Assem2.STEP
45.5 x 17.0 x 58.5 mm
pcb
middal plat
top cover
bottem plat
switch 2
battry
butten

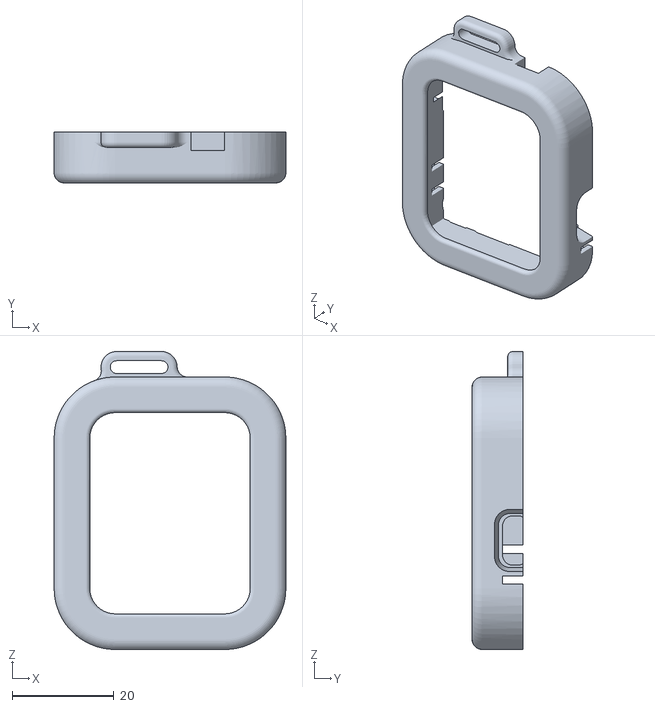
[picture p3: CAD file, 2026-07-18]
3D Print Files /Assem2 - Top cover-1.STL
45.5 x 10.00 x 58.5

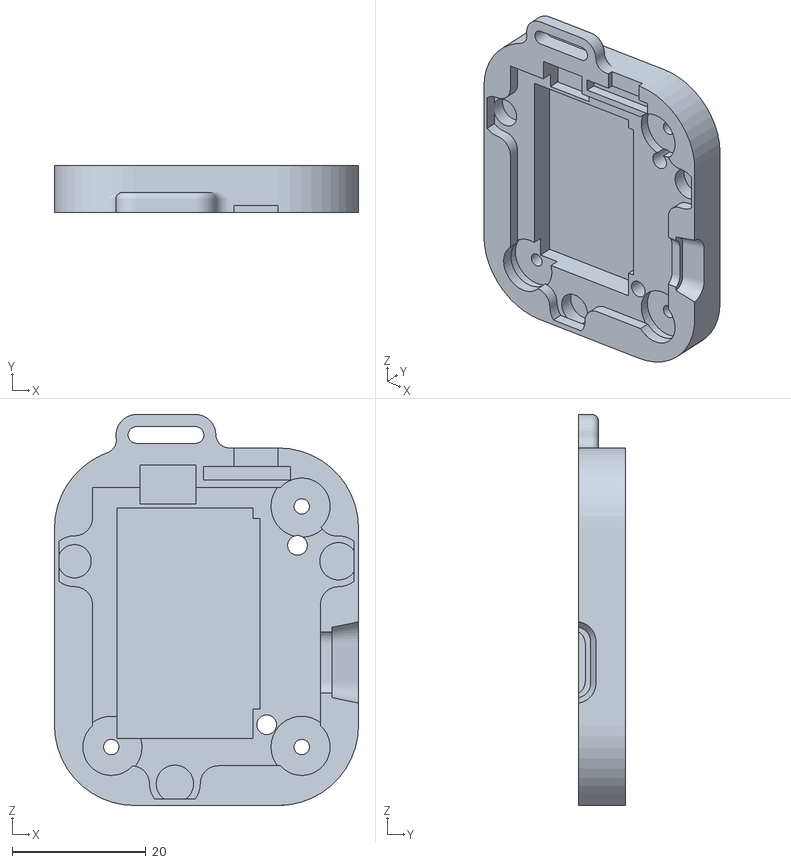
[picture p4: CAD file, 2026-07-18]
3D Print Files /Assem2 - bottom plate-1.STL
45.5 x 7.00 x 58.5

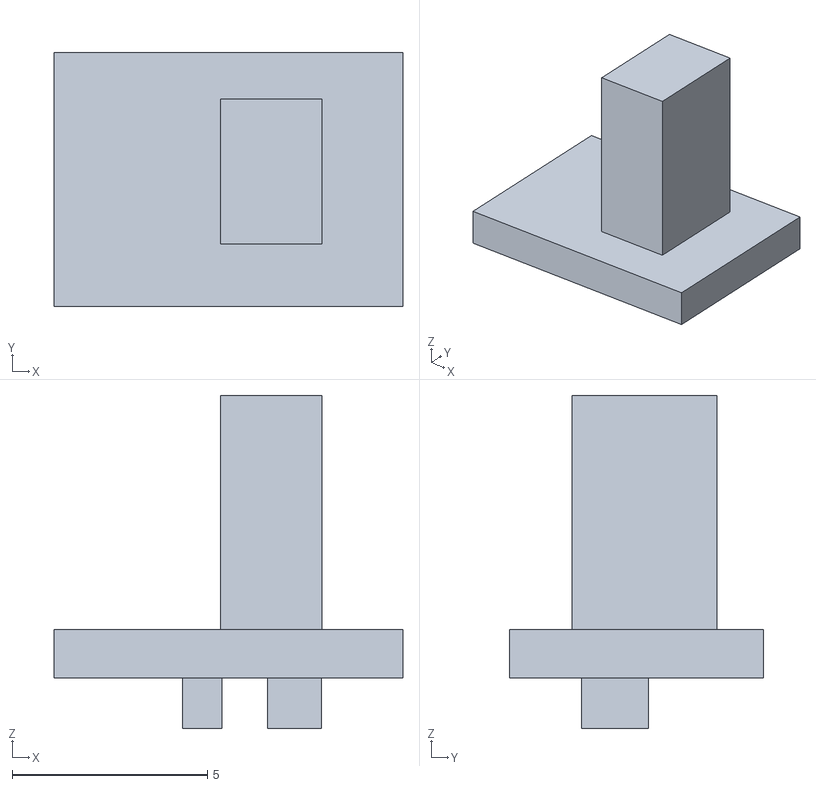
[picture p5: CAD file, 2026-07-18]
3D Print Files /Assem2 - OnOff switch 2-1.STL
8.94 x 6.50 x 8.54

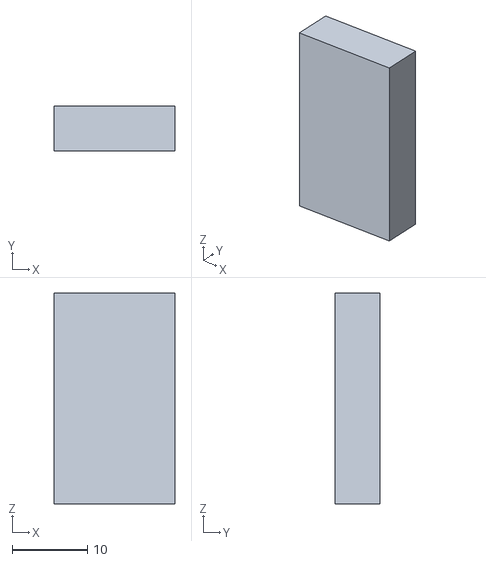
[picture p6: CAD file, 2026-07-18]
3D Print Files /Assem2 - battery-1.STL
16.0 x 6.00 x 28.0

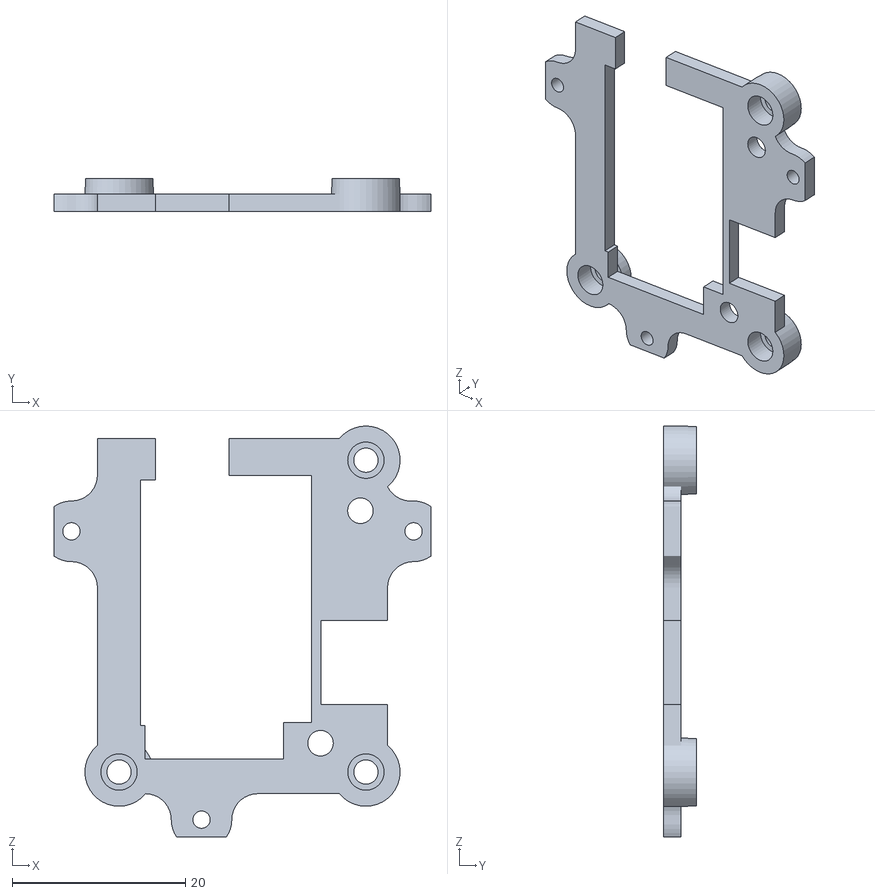
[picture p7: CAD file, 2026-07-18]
3D Print Files /Assem2 - middel plate.STL
43.5 x 3.80 x 47.5

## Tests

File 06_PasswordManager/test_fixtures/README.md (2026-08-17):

# Test fixtures

`bitwarden_export_sample.json` — a small, fully fake Bitwarden vault export
used to manually test the Bitwarden import feature (Settings → Import →
Bitwarden). See [docs/BITWARDEN_IMPORT.md](../../docs/BITWARDEN_IMPORT.md)
for the full test procedure.

**All data in this file is fake** — `*.example.invalid` domains (a reserved,
non-resolvable TLD per RFC 2606) and obviously-placeholder passwords
(`Demo-Pass-NNNN!`). Never replace this fixture with real account data.

Contents, exercising every case the importer needs to handle:

| Case | Count | Where |
|---|---|---|
| Logins | 5 | items[0..4] |
| Secure Notes | 2 | items[5..6] |
| Folders | 2 | folders[] |
| Intentional duplicate (same title+username+URL) | 1 | items[0] and items[4] are identical |
| Custom field | 1 | items[2].fields[0] ("Security Question") |
| TOTP secret | 1 | items[1].login.totp |
| Multiple URIs on one item | 1 | items[1].login.uris (2 entries) |
| Unsupported item type (Identity) | 1 | items[7] |
| Item with no folder (`folderId: null`) | 3 | items[2], items[6], items[7] |

This project has no automated test harness (it's Arduino firmware, tested
manually against real hardware — see `docs/SECURITY.md`'s own testing
section for the same convention). This fixture is meant to be uploaded
through the on-device Bitwarden import flow during manual testing, not run
through a CI test suite.

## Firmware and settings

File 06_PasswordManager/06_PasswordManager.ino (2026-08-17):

/*
 * SecureKey — Hardware Password Manager  (monochrome edition)
 * ─────────────────────────────────────────────────────────────────────
 *  Board   : MaTouch ESP32-S3 AMOLED 1.8"  (368×448, SH8601 QSPI)
 *  Touch   : FT3168 capacitive
 *  Store   : FFat /db.bin   (256 B/record × MAX_PASSWORDS = 30000)
 *  Setings : NVS  "skset" namespace
 *
 *  Screens:
 *     LOCK  →  PIN  →  HOME (2x2 icon grid, drag-to-reorder)
 *                          ├─ PASSWORDS  → list (inline search) → DETAIL
 *                          ├─ ADD NEW    → form
 *                          ├─ FAVORITES  → list (hearts only)
 *                          └─ SETTINGS   → Bluetooth / USB / Brightness / …
 *
 *  HID typing goes out over BLE (paired phone/PC) AND/OR USB-C — both
 *  transports can be live at once.
 *  Capacity: up to 30,000 passwords (MAX_PASSWORDS in theme.h).
 * ─────────────────────────────────────────────────────────────────────
 */
// ── HID configuration ───────────────────────────────────────────────
//
//   USB and BLE HID live in separate .cpp files (hid_usb.cpp,
//   hid_ble.cpp) because the libraries define the same KEY_xxx
//   macros and can't be in the same translation unit.  This file
//   only sees extern "C" wrappers — no library headers leak in.
//
//   To disable a transport at compile time, set HID_USB_ENABLE 0 in
//   hid_usb.cpp  or  HID_BLE_ENABLE 0 in hid_ble.cpp.
//
//   At runtime, Settings → Bluetooth and Settings → USB HID toggle
//
extern "C" {
  void hidUsbBegin();
  void hidUsbPrint(const char *s);
  void hidUsbQuickFill(const char *user, const char *pass);
  int  hidUsbCompiled();
  int  hidUsbMounted();    // 1 once a USB host has enumerated the keyboard
  void hidUsbSetAndroidFix(int on);   // UK/Android @<->" keycode swap (USB)

  void hidBleBegin();
  void hidBleEnd();
  int  hidBleConnected();
  void hidBlePrint(const char *s);
  void hidBleQuickFill(const char *user, const char *pass);
  int  hidBleCompiled();
  int  hidBleStarted();
  void hidBleSetAndroidFix(int on);   // UK/Android @<->" keycode swap
  void hidBlePeerAddr(char *out, int n);   // connecting peer's BT address
  int  hidBlePeerIdAddr(char *out, int n, int *type);  // 1=bonded/stable id
  int  hidBleCapturePeer(char *ota, int otaN, char *id, int idN,
                         int *type, int *bonded);       // one-shot peer snapshot
  void hidBleForgetOne(const char *addr, int type);    // delete one bond
  void hidBleSettleReset();           // re-arm typing settle on disconnect
  void hidBleTune();                  // request tight conn interval at connect
  void hidBleTuneCached();            // same, but by cached handle (no list copy)
  void hidBleDisconnectCached();      // disconnect by cached handle (no list copy)
  void hidBleForget();                // clear all BLE bonds (re-pair fresh)
  void hidBleDisconnectPeer();        // kick current peer, keep advertising
  void hidBleReadvertise();           // restart advertising after a disconnect
  void hidBleReturn();                // send Return key over BLE
  void hidUsbReturn();                // send Return key over USB

  // Consumer Control (media key) HID — see media_control.ino for the
  // transport-agnostic mediaVolumeUp()/etc. wrappers built on top of these.
  // Deliberately independent of vaultUnlocked/bleAuthorized: media keys work
  // whether the vault is locked or not, same as any standalone BT/USB remote.
  void hidConsumerUsbBegin();
  int  hidConsumerUsbReady();          // 1 once the USB host has enumerated us
  int  hidConsumerUsbCompiled();
  void hidConsumerUsbMediaKey(int code);

  int  hidBleMediaReady();             // 1 once a BLE HID host is connected
  void hidBleMediaKey(int code);
}

#include <Arduino.h>
#include <Wire.h>
#include <Arduino_GFX_Library.h>
#include <Adafruit_NeoPixel.h>
#include <FFat.h>
#include <Preferences.h>
#include <WiFi.h>           // WiFiEvent_t/WiFiEventInfo_t — wifi_portal.ino's
                            // diagnostic event callback takes these by value;
                            // needs to be visible before Arduino's hoisted
                            // prototypes, same reasoning as bw_json_parser.h
                            // below (wifi_portal.ino itself also includes
                            // <WiFi.h>, but that's too late for hoisting).
#include "pin_config.h"
#include "theme.h"
#include "esp_system.h"     // esp_reset_reason() — logged at boot
#include "crypto_core.h"    // PBKDF2 / AES-256-GCM / CSPRNG / secure-wipe wrappers
#include "shared_types.h"      // encrypted-DB on-disk layout + SECURITY_VERSION
#include "bw_json_parser.h"    // Bitwarden streaming-JSON-parser types (BwParsedItem/
                                // BwParsedFolder/BwParserState) — included early, same
                                // reasoning as shared_types.h: bw_import.ino's functions
                                // take these structs by reference, and Arduino's auto-
                                // prototype hoisting needs the types visible before that,
                                // regardless of which file actually defines them.

// vault_crypto.ino's vaultPinLength() is used a few lines below (in
// pinRefreshLength()) — earlier than Arduino's auto-generated function
// prototypes get inserted, so it needs an explicit forward declaration up
// here rather than relying on the (correctly, but too-late-positioned)
// one further down with the rest of this file's forward declarations.
uint8_t vaultPinLength();

// HID transports are isolated to hid_usb.cpp / hid_ble.cpp — see above

// ── Hardware objects ─────────────────────────────────────────────────
Arduino_DataBus *bus = new Arduino_ESP32QSPI(
    LCD_CS, LCD_SCK, LCD_SDIO0, LCD_SDIO1, LCD_SDIO2, LCD_SDIO3);
Arduino_GFX    *out = new Arduino_SH8601(
    bus, LCD_RST, 0, false, LCD_WIDTH, LCD_HEIGHT);
Arduino_Canvas *gfx = new Arduino_Canvas(LCD_WIDTH, LCD_HEIGHT, out);
Adafruit_NeoPixel led(RGB_LED_COUNT, RGB_LED_PIN, NEO_GRB + NEO_KHZ800);
Preferences      prefs;

inline void flushScreen() { gfx->flush(); }

// ── Navigation stack ─────────────────────────────────────────────────
Screen   navStack[10] = { SCR_LOCK };
int8_t   navTop       = 0;
Screen   current      = SCR_LOCK;

// ── Global state ─────────────────────────────────────────────────────
// BLE connection state (polled in loop, drawn by the status bar)
bool     btConnected = false;

// BLE pairing gate: a phone can connect, but the device types NOTHING until
// the user taps "Accept" on the on-device request prompt (which only appears
// after the PIN has been entered / device unlocked). "Block 5 min" puts BLE
// dark for 5 minutes so a pushy host stops re-requesting.
bool     bleAuthorized  = false;          // true once the user accepts this connection
uint32_t bleBlockUntil  = 0;             // millis() until which this peer is silently kicked
uint32_t bleGateSnooze  = 0;            // after REJECT: don't re-prompt before this
char     bleBlockedAddr[24] = {0};       // MAC of the specifically blocked peer

// Saved BLE devices ("whitelist"): devices the user accepted once are
// remembered by identity address and auto-approved on reconnect — no
// repeated Accept prompt. Managed on the Devices screen (Settings → Devices).
SavedDevice savedDevs[MAX_BLE_DEVICES];
uint8_t     savedDevCount = 0;

// Cached identity of the currently-connected BLE peer. Updated ONCE per BLE
// manager tick from the main loop; the Devices screen and auto-approve read
// these instead of calling NimBLE per-draw (which raced the NimBLE core-0 task
// and reset the device whenever the Devices screen was open).
char        connPeerId[18]  = {0};   // resolved identity, or "" if none/unbonded
char        connPeerOta[24] = {0};   // over-the-air address (for the gate display)
int         connPeerType    = 0;
bool        connPeerBonded  = false;
bool        connPeerCaptured = false; // got a snapshot for this connection?

// User pressed DISCONNECT on the Devices screen: BLE is fully PAUSED — link
// dropped AND advertising stopped — until they press CONNECT. Pausing the
// radio (instead of kicking the phone every time it auto-reconnects, as the
// old per-device pause did) is what keeps iOS sane: the kick-on-reconnect
// loop made the phone flap — "connected" in its settings, typed nothing,
// dropped, retried — until the user had to Forget the device. RAM-only;
// cleared by CONNECT, the Bluetooth toggle, or a reboot.
bool        bleUserPaused = false;

void devsSave() {
  prefs.begin("skset", false);
  prefs.putBytes("devs", savedDevs, (size_t)savedDevCount * sizeof(SavedDevice));
  prefs.end();
}
void devsLoad() {
  prefs.begin("skset", true);
  size_t n = prefs.getBytesLength("devs");
  savedDevCount = 0;
  if (n > 0 && n % sizeof(SavedDevice) == 0 && n <= sizeof(savedDevs)) {
    prefs.getBytes("devs", savedDevs, n);
    savedDevCount = (uint8_t)(n / sizeof(SavedDevice));
  }
  prefs.end();
}
int devsFind(const char *addr) {
  for (uint8_t i = 0; i < savedDevCount; i++)
    if (strcasecmp(savedDevs[i].addr, addr) == 0) return i;
  return -1;
}
void devsAdd(const char *addr, int type) {
  if (!addr || !addr[0] || strcmp(addr, "unknown") == 0) return;
  if (devsFind(addr) >= 0) return;                  // already saved
  if (savedDevCount >= MAX_BLE_DEVICES) {           // full → drop the oldest
    memmove(&savedDevs[0], &savedDevs[1],
            (MAX_BLE_DEVICES - 1) * sizeof(SavedDevice));
    savedDevCount = MAX_BLE_DEVICES - 1;
  }
  SavedDevice &d = savedDevs[savedDevCount++];
  memset(&d, 0, sizeof(d));
  strncpy(d.addr, addr, sizeof(d.addr) - 1);
  d.addrType = (uint8_t)type;
  // Default alias: "Device EE:FF" (address tail) until the user renames it.
  const char *tail = strlen(addr) >= 5 ? addr + strlen(addr) - 5 : addr;
  snprintf(d.name, sizeof(d.name), "Device %s", tail);
  devsSave();
  SK_LOG("[BLE] saved device %s as '%s'\n", d.addr, d.name);
}
void devsRemove(uint8_t idx) {
  if (idx >= savedDevCount) return;
  hidBleForgetOne(savedDevs[idx].addr, savedDevs[idx].addrType);
  memmove(&savedDevs[idx], &savedDevs[idx + 1],
          (size_t)(savedDevCount - idx - 1) * sizeof(SavedDevice));
  savedDevCount--;
  devsSave();
}

// PIN — buffer sized for PIN_MAX_LEN (8) digits + NUL. The PIN itself
// never touches NVS/Preferences; see vault_crypto.ino. This buffer is
// wiped with ckSecureZero() after every unlock/setup/change attempt.
char     pinEntry[PIN_MAX_LEN + 1] = {0};
uint8_t  pinLen      = 0;
uint32_t shakeUntil  = 0;
uint32_t unlockUntil = 0;

// Cached configured PIN length (how many digits the keypad should collect
// before auto-submitting) — refreshed from NVS metadata at boot / after
// a PIN change. See vaultPinLength()/vaultSetPinLength() in vault_crypto.ino.
uint8_t  cachedPinLen = PIN_MIN_LEN;
uint8_t  pinDisplayLen() { return cachedPinLen; }
void     pinRefreshLength() { cachedPinLen = vaultPinLength(); }

// PIN brute-force lockout (escalating wait after repeated wrong PINs)
uint8_t  pinFails     = 0;       // cumulative wrong attempts (persisted)
uint32_t pinLockUntil = 0;       // millis() until which the keypad is frozen

// Touch state (used by touch_input.ino)
bool     touching    = false;
uint16_t tStartX, tStartY, tCurX, tCurY;
uint32_t tStartTime  = 0;
bool     isDrag      = false;
const int16_t DRAG_THRESHOLD = 14;

// Password DB
ListItem  *passwordIndex = nullptr;
uint16_t   passwordCount = 0;

// List screen state
int32_t   listScrollY  = 0;
float     listVelocity = 0.0f;

// Selected/Editing
uint16_t  detailId  = 0;     // currently shown
uint16_t  editingId = 0;     // 0 = adding new

// User settings (loaded from NVS) — USB HID defaults ON so typing works
// out-of-the-box when plugged into a PC. No PIN field here — see theme.h.
UserSettings settings = { 140, false, true, 30, false };

// Idle tracking for auto-lock (refreshed on every touch in pollTouch)
uint32_t   lastActivityMs = 0;

// Screen-off state (side button only — automated sleep modes were removed:
// idle light-sleep / double-tap sleep read as "touch randomly stops working"
// in QA, because the dark panel + double-tap-to-wake looked like dead touch).
bool       screenOff   = false;

// LED helper
uint32_t  ledClearAt = 0;
void ledSet(uint32_t c, uint32_t ms = 300) {
  led.setPixelColor(0, c); led.show(); ledClearAt = millis() + ms;
}
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
void loop() {
  // WiFi captive-portal import: service the AP + web server when active.
  // Safety: if we've navigated away from EVERY screen that legitimately
  // keeps the portal up (the general manager's SCR_WIFI, or any step of the
  // Bitwarden-import flow, which reuses the SAME portal instance in a
  // restricted "import mode" — see wifi_portal.ino), shut the portal down.
  bool onPortalScreen = (current == SCR_WIFI || current == SCR_IMPORT_WAIT ||
                        current == SCR_IMPORT_PREVIEW || current == SCR_IMPORT_PROGRESS ||
                        current == SCR_IMPORT_DONE);
  if (wifiPortalActive() && !onPortalScreen) wifiPortalStop();
  wifiPortalLoop();

  // Lock screen: ~2 Hz repaint for the "tap to unlock" pulse
  static uint32_t lastLockMs = 0;
  if (current == SCR_LOCK && millis() - lastLockMs > 500) {
    lastLockMs = millis();
    drawLock();
  }

  // PIN shake animation (~20 Hz)
  static uint32_t lastShakeMs = 0;
  if (current == SCR_PIN && millis() < shakeUntil
      && millis() - lastShakeMs > 50) {
    lastShakeMs = millis();
    drawPin();
  }

  // PIN lockout countdown (~2 Hz). Keeps the "Wait Ns" ticking and repaints
  // the keypad once the wait expires.
  static uint32_t lastPinLockMs = 0;
  static bool     pinWasLocked  = false;
  if (current == SCR_PIN && millis() - lastPinLockMs > 500) {
    bool locked = pinLockRemaining() > 0;
    if (locked || pinWasLocked) {
      lastPinLockMs = millis();
      pinWasLocked  = locked;
      drawPin();
    }
  }

  // (UNLOCKED splash removed — PIN screen jumps straight to HOME)

  // List inertia scroll (only when not in search mode). Capped at ~45 Hz
  // (was ~60 Hz) — each tick is a FULL list redraw (drawList() clears and
  // repaints the whole screen, then Arduino_Canvas::flush() blits the
  // entire 368x448 framebuffer over QSPI; the library has no partial/
  // dirty-rect blit to opt into), so this is real CPU/bus time saved on
  // every fling. 45 Hz is still well above what the eye can distinguish
  // from 60 Hz for a decelerating scroll, and the decay curve/feel is
  // untouched — same 0.86 per-tick multiplier, just fired slightly less
  // often, so a fling settles in the same number of *visible* steps.
  if (current == SCR_LIST && !listSearchMode &&
      fabsf(listVelocity) > 0.5f) {
    static uint32_t lastInertia = 0;
    if (millis() - lastInertia > 22) {
      lastInertia = millis();
      listScroll((int16_t)listVelocity);
      listVelocity *= 0.86f;
    }
  }

  // SW2 physical → screen on/off toggle. Press to turn the screen OFF
  // (locked + dark, touch ignored); press again to turn it back ON.
  // This is the ONLY sleep-like mode left — no idle sleep, no double-tap.
  static bool btnLast = HIGH;
  bool btnNow = digitalRead(USER_BTN_PIN);
  if (btnLast == HIGH && btnNow == LOW) {
    if (screenOff) {
      out->Display_Brightness(settings.brightness);
      screenOff = false;
      lastActivityMs = millis();     // fresh idle window on wake
    } else {
      screenSleep();
    }
  }
  btnLast = btnNow;

  // LED auto-clear
  if (ledClearAt && millis() > ledClearAt) {
    led.clear(); led.show(); ledClearAt = 0;
  }

  // Touch ~60 Hz
  static uint32_t lastTouchMs = 0;
  if (millis() - lastTouchMs > 16) {
    lastTouchMs = millis();
    pollTouch();
  }

  // BLE manager ~2 Hz: keep advertising in the right state (live toggle, no
  // reboot), refresh the status icon, and surface the Accept/Reject/Block
  // prompt on a new connection — but only once the device is unlocked, so the
  // request appears *after* the PIN is entered.
  //
  // MUST stay fully suppressed while the WiFi import portal is active —
  // wifiPortalStartCommon() (wifi_portal.ino) deliberately calls hidBleEnd()
  // before bringing up the SoftAP specifically because WiFi + BLE share ONE
  // 2.4 GHz radio, and running both at once is a documented reset trigger on
  // this hardware (see that function's "Restart-bug mitigation" comment).
  // Without this guard, THIS block would see hidBleStarted()==false a
  // moment later (since the WiFi code just turned it off) and — if the user
  // has Bluetooth enabled in Settings, which is a completely ordinary
  // setting — call hidBleBegin() right back on its own next ~2 Hz tick,
  // fighting the WiFi code's radio-safety decision on every single loop()
  // pass for as long as the portal stayed up. That is a REAL, confirmed bug
  // (not a guess): a physical serial capture during a Bitwarden import
  // showed exactly "[WIFI] stopping BLE before AP" followed moments later
  // by "[BLE] resume advertising" — this block re-enabling it — followed by
  // a PANIC reset during the upload, with the exact byte offset varying
  // run-to-run (consistent with a timing-dependent race against this ~2 Hz
  // tick, not a fixed line in the upload/parse code). wifiPortalStop()
  // already explicitly restores BLE once the portal actually ends (its own
  // "resuming BLE after AP" log line) — that single restore point is
  // correct and sufficient; this block must not compete with it while a
  // portal session is live.
  static uint32_t lastBleMs = 0;
  if (millis() - lastBleMs > 500 && !wifiPortalActive()) {
    lastBleMs = millis();

    if (hidBleCompiled()) {
      // Advertise whenever BLE is enabled AND the device is awake AND the
      // user hasn't paused it from the Devices screen. In sleep (screenOff)
      // BLE is forced off to save battery; it resumes on wake.
      bool wantBle = settings.bleEnabled && !screenOff && !bleUserPaused;
      if (wantBle && !hidBleStarted())  hidBleBegin();
      if (!wantBle && hidBleStarted()) { hidBleEnd(); bleAuthorized = false; }
    }

    static uint32_t connRisingAt = 0;
    static bool     connTuned    = false;
    bool nowConn = settings.bleEnabled && hidBleCompiled() && hidBleConnected();
    if (nowConn && !btConnected) {                          // rising edge
      connRisingAt = millis();
      connTuned = false;   // (re)tune once we've safely captured the handle
      // NOTE: no hidBleTune() here anymore — it copied the connection list at
      // the connect instant (peak churn), a reset source. We tune by cached
      // handle right after the capture below instead.
    }
    if (nowConn != btConnected) {
      if (btConnected && !nowConn) {
        // Disconnect edge: give a quiet window so a phone that auto-reconnects
        // the instant it drops can't immediately re-fire the Accept gate
        // ("requests keep coming"). A deliberate re-pair still works after 3 s.
        bleGateSnooze = millis() + 3000;
      }
      btConnected = nowConn;
      if (current == SCR_DEVICES)      drawAll();   // live card/list update
      else if (current != SCR_FLASH) { drawStatusBar(); flushScreen(); }
    }
    if (!nowConn) {                        // peer dropped (or never connected)
      bleAuthorized = false;
      hidBleSettleReset();
      // NimBLE re-advertises itself on disconnect (advertiseOnDisconnect) — no
      // manual restart needed here anymore.
    }

    // Snapshot the connected peer into the cache. We query NimBLE's connection
    // list ONLY until we've captured a bonded identity, and at most for the
    // first ~5 s after connecting — after that we never touch the list again
    // for this connection. Everything else (gate, auto-approve, Devices screen,
    // block check) reads the cached strings. This is the fix for the random
    // PANIC: getPeerDevices() copies a vector the BLE core mutates on
    // connect/disconnect, so calling it constantly (per redraw) eventually
    // read freed memory and reset the device. Steady state now = zero reads.
    if (nowConn) {
      // Keep snapshotting only for the first 8 s of a connection, and stop
      // early once we have a bonded identity. After that: never query again.
      bool tryCapture = (millis() - connRisingAt < 8000) && !connPeerBonded;
      if (tryCapture) {
        char ota[24], id[18]; int t = 0, b = 0;
        if (hidBleCapturePeer(ota, sizeof(ota), id, sizeof(id), &t, &b)) {
          strncpy(connPeerOta, ota, sizeof(connPeerOta) - 1); connPeerOta[sizeof(connPeerOta) - 1] = 0;
          strncpy(connPeerId,  id,  sizeof(connPeerId)  - 1); connPeerId[sizeof(connPeerId)   - 1] = 0;
          connPeerType   = t;
          connPeerBonded = b ? true : false;
          connPeerCaptured = true;
          if (!connTuned) { hidBleTuneCached(); connTuned = true; }  // safe: by handle
        }
      }
    } else {
      connPeerId[0] = 0; connPeerOta[0] = 0;
      connPeerBonded = false; connPeerType = 0; connPeerCaptured = false;
      connTuned = false;
    }
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

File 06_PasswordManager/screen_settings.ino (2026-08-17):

// =============================================================
//  screen_settings.ino  —  Settings list
//
//  Items (smartwatch-style):
//    • Bluetooth         (toggle — live, no reboot)
//    • Devices           (saved BLE devices — rename/disconnect/forget)
//    • USB HID           (toggle)
//    • Android           (toggle — @/" keycode swap)
//    • Auto-Lock         (value — idle re-lock; screen stays on)
//    • Brightness        (slider, 20–250)
//    • Change PIN        (action)
//    • Test HID Now      (action)
//    • Import             (action — opens a submenu: General WiFi Manager
//                          or Bitwarden Import, see screen_import.ino)
//    • About             (info)
//    • Factory Reset     (action — PIN-gated)
// =============================================================

#define SET_LIST_TOP   (STATUS_H + NAV_H + 10)
#define SET_TOGGLE_W   60      // bigger tap target
#define SET_TOGGLE_H   30

void typeViaHID(const char *s);   // defined in 06_PasswordManager.ino

// ── Scrolling support ────────────────────────────────────────
int32_t  settingsScrollY = 0;
#define  SET_ROW_COUNT   11
#define  SET_ROW_STEP    (SET_ITEM_H + 8)

// Right-aligned value labels for the "value + chevron" rows
static const char* autoLockLabel() {
  switch (settings.autoLockSec) {
    case 0:   return "Off";
    case 15:  return "15s";
    case 30:  return "30s";
    case 60:  return "1m";
    case 120: return "2m";
    default:  return "30s";
  }
}
static inline int32_t setMaxScroll() {
  int32_t visible = LCD_HEIGHT - SET_LIST_TOP - 8;
  int32_t total   = SET_ROW_COUNT * SET_ROW_STEP;
  return total > visible ? total - visible : 0;
}
void setScroll(int16_t dy) {
  int32_t y = settingsScrollY + (int32_t)dy;
  int32_t maxS = setMaxScroll();
  if (y < 0)    y = 0;
  if (y > maxS) y = maxS;
  settingsScrollY = y;
  drawSettings();
}

static void drawToggle(int16_t x, int16_t y, bool on) {
  // iOS-style pill: blue track + white knob when ON, dark track when OFF.
  uint16_t bg     = on ? C_BLUE   : C_GRAY_1;
  uint16_t border = on ? C_BLUE   : C_GRAY_3;
  uint16_t knob   = C_WHITE;

  gfx->fillRoundRect(x, y, SET_TOGGLE_W, SET_TOGGLE_H,
                     SET_TOGGLE_H/2, bg);
  gfx->drawRoundRect(x, y, SET_TOGGLE_W, SET_TOGGLE_H,
                     SET_TOGGLE_H/2, border);
  int16_t knobX = on ? x + SET_TOGGLE_W - SET_TOGGLE_H + 2
                     : x + 2;
  gfx->fillCircle(knobX + SET_TOGGLE_H/2 - 2,
                  y + SET_TOGGLE_H/2,
                  SET_TOGGLE_H/2 - 4, knob);
}

static void drawSlider(int16_t x, int16_t y, int16_t w, uint8_t val,
                       uint8_t minV, uint8_t maxV) {
  int16_t h = 8;
  int16_t sy = y + (24 - h) / 2;
  gfx->fillRoundRect(x, sy, w, h, h/2, C_GRAY_1);
  gfx->drawRoundRect(x, sy, w, h, h/2, C_GRAY_3);
  int16_t fillW = (int16_t)((int32_t)(val - minV) * w / (maxV - minV));
  gfx->fillRoundRect(x, sy, fillW, h, h/2, C_BLUE);

  // Knob
  int16_t knobX = x + fillW;
  gfx->fillCircle(knobX, sy + h/2, 8, C_WHITE);
  gfx->drawCircle(knobX, sy + h/2, 8, C_GRAY_3);
}

static void drawSetRow(int16_t y, const char *label, uint8_t kind,
                       bool boolVal = false, uint8_t numVal = 0,
                       const char *valStr = nullptr) {
  int16_t x = SAFE_PAD;
  int16_t w = LCD_WIDTH - 2*SAFE_PAD;
  gfx->fillRoundRect(x, y, w, SET_ITEM_H, 10, C_GRAY_1);
  gfx->drawRoundRect(x, y, w, SET_ITEM_H, 10, C_GRAY_2);

  // Left accent bar — red for the destructive row, blue otherwise
  bool danger = (strcmp(label, "Factory Reset") == 0);
  gfx->fillRoundRect(x + 8, y + 14, 4, SET_ITEM_H - 28, 2,
                     danger ? C_RED : C_BLUE);

  // Label
  gfx->setTextSize(2); gfx->setTextColor(danger ? C_RED : C_WHITE);
  gfx->setCursor(x + 22, y + (SET_ITEM_H - 14) / 2);
  gfx->print(label);

  // Right control
  if (kind == 0) { // toggle
    drawToggle(x + w - SET_TOGGLE_W - 12,
               y + (SET_ITEM_H - SET_TOGGLE_H) / 2, boolVal);
  } else if (kind == 1) { // slider
    drawSlider(x + w/2, y + (SET_ITEM_H - 24)/2, w/2 - 14,
               numVal, 20, 250);
  } else if (kind == 2) { // chevron
    gfx->setTextSize(2); gfx->setTextColor(C_GRAY_3);
    gfx->setCursor(x + w - 22, y + (SET_ITEM_H - 14) / 2);
    gfx->print(">");
  } else if (kind == 3) { // value + chevron
    if (valStr) {
      gfx->setTextSize(2); gfx->setTextColor(C_BLUE);
      int16_t x1, y1; uint16_t tw, th;
      gfx->getTextBounds(valStr, 0, 0, &x1, &y1, &tw, &th);
      gfx->setCursor(x + w - 32 - (int16_t)tw, y + (SET_ITEM_H - 14) / 2);
      gfx->print(valStr);
    }
    gfx->setTextSize(2); gfx->setTextColor(C_GRAY_3);
    gfx->setCursor(x + w - 22, y + (SET_ITEM_H - 14) / 2);
    gfx->print(">");
  }
}
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

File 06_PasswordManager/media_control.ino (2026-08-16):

// =============================================================
//  media_control.ino  —  Transport-agnostic Consumer Control (media key)
//  abstraction: mediaVolumeUp() / mediaVolumeDown() / mediaMute() /
//  mediaPlayPause() / mediaPrevious() / mediaNext()
//
//  Mirrors the existing typeViaHID()/quickFillViaHID() pattern (same "pick
//  BLE if connected+enabled, else USB, else nothing" transport choice) but
//  is DELIBERATELY independent of bleAuthorized/vaultUnlocked: a media
//  remote (this device, in Media mode) works whether or not the password
//  vault is unlocked — exactly like pressing the volume keys on any
//  standalone Bluetooth/USB media remote. See hid_ble.cpp's and
//  hid_usb.cpp's file-header notes, written specifically to flag this
//  design constraint before this file existed.
//
//  Sends REAL HID Consumer Control usages (Volume Increment 0x00E9, Mute
//  0x00E2, Play/Pause 0x00CD, Scan Next/Previous 0x00B5/0x00B6, ...) — never
//  keyboard-shortcut simulation (no Fn combos, no F7/F8/F9 substitution).
//
//  ── Local volume state — READ THIS BEFORE TRUSTING THE PERCENTAGE ──
//  USB/BLE Consumer Control is a ONE-WAY, edit-only protocol: the host OS
//  applies "increment/decrement/mute" to whatever its current volume is,
//  but never reports that value back to an external HID device — there is
//  no "get system volume" usage in the Consumer Control page, and neither
//  BleKeyboard nor USBHIDConsumerControl exposes an inbound-report/feature
//  path SecureKey could use to ask. So `mediaVolumeLocal` below is a LOCAL
//  ESTIMATE only: it starts at 50%, moves by MEDIA_VOL_STEP per tap, and
//  clamps to [0,100] — it can and will drift out of sync with the host's
//  actual volume (host-side app volume, a hardware volume knob, another
//  input device, an OS volume limit, etc. are all invisible to us). The UI
//  must present it as "your estimate", not "the real volume" — see
//  screen_media.ino's subtitle text. If a future transport/library exposes
//  real host-volume feedback, that should replace this estimate; nothing
//  else in this file's public API would need to change.
// =============================================================

// ── Consumer-key codes — MUST match the MEDIA_KEY_* enum in hid_ble.cpp and
// hid_consumer_usb.cpp exactly (kept as parallel local enums there rather
// than a shared header, since both are tiny extern "C" leaf files that
// otherwise pull in zero project headers beyond theme.h).
enum {
  MK_VOLUME_UP = 0,
  MK_VOLUME_DOWN,
  MK_MUTE,
  MK_PLAY_PAUSE,
  MK_PREV_TRACK,
  MK_NEXT_TRACK,
};

#define MEDIA_VOL_STEP   5      // % moved per Volume +/- tap (local estimate only)
#define MEDIA_VOL_INIT   50     // reasonable starting guess — see file header

// ── Local UI state (estimate only — see file header) ───────────────────
int8_t  mediaVolumeLocal = MEDIA_VOL_INIT;   // 0..100
bool    mediaMuted       = false;
bool    mediaPlaying     = false;   // best-effort local toggle — see mediaPlayPause()

// True if EITHER transport is currently able to carry a media key. Lets the
// UI show a "not connected" hint without needing to know which transport.
bool mediaTransportReady() {
  if (settings.bleEnabled && hidBleCompiled() && hidBleMediaReady()) return true;
  if (settings.usbHidEnabled && hidConsumerUsbCompiled() && hidConsumerUsbReady()) return true;
  return false;
}

// One place that actually dispatches a Consumer Control usage over
// whichever transport is live. Same "BLE first, then USB" precedence as
// typeViaHID() for consistency, but with NO bleAuthorized/vaultUnlocked
// gate — see file header.
static void mediaSend(int code) {
  if (settings.bleEnabled && hidBleCompiled() && hidBleMediaReady()) {
    hidBleMediaKey(code);
    ledSet(0x0000FF, 120);
    return;
  }
  if (settings.usbHidEnabled && hidConsumerUsbCompiled() && hidConsumerUsbReady()) {
    hidConsumerUsbMediaKey(code);
    ledSet(0x00FF00, 120);
    return;
  }
  // No transport ready — silently a no-op (screen_media.ino shows a
  // persistent "not connected" hint instead of an interrupting modal, since
  // media controls are meant to be tapped quickly/repeatedly).
}

static int8_t clampVol(int v) {
  if (v < 0)   return 0;
  if (v > 100) return 100;
  return (int8_t)v;
}

void mediaVolumeUp() {
  mediaVolumeLocal = clampVol(mediaVolumeLocal + MEDIA_VOL_STEP);
  if (mediaVolumeLocal > 0) mediaMuted = false;   // raising volume implies unmuted
  mediaSend(MK_VOLUME_UP);
}

void mediaVolumeDown() {
  mediaVolumeLocal = clampVol(mediaVolumeLocal - MEDIA_VOL_STEP);
  mediaSend(MK_VOLUME_DOWN);
}

void mediaMute() {
  mediaMuted = !mediaMuted;
  mediaSend(MK_MUTE);
}

void mediaPlayPause() {
  // Best-effort local toggle for the icon only — we have no way to know the
  // host's actual playback state (same one-way-protocol limitation as
  // volume). Good enough for "does the icon look right most of the time";
  // never treat this as ground truth.
  mediaPlaying = !mediaPlaying;
  mediaSend(MK_PLAY_PAUSE);
}

void mediaPrevious() {
  mediaSend(MK_PREV_TRACK);
}

void mediaNext() {
  mediaSend(MK_NEXT_TRACK);
}

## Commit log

2026-07-18 3D Files Updated
    [Assem2 - OnOff switch 2-1.STL, Assem2 - Top cover-1.STL, Assem2 - battery-1.STL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]
2026-08-16 secure code and build.yaml
    [partitions_securekey_prod.csv]
2026-08-16 Add media/volume controller mode
    Adds a second device mode alongside the password manager: a touchscreen
    media/volume remote (volume +/-, mute, play/pause, previous/next) that
    becomes the default resting screen. The vault stays locked the entire
    time this screen is shown.
    - media_control.ino: transport-agnostic mediaVolumeUp()/mediaVolumeDown()/
    mediaMute()/mediaPlayPause()/mediaPrevious()/mediaNext() wrappers, plus
    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
2026-08-17 Add debug timing log around PBKDF2 unlock derivation
    Diagnosing a reported ~15s hang after PIN entry on real hardware, vs the
    code comment's untested "~150-300ms measured on S3" estimate for
    CK_PBKDF2_ITERATIONS (50000). Logs elapsed ms for the PBKDF2-HMAC-SHA256
    call in vaultUnlock() via SK_LOG (SECUREKEY_DEBUG-gated, no PIN/key
    material logged) so the real per-device cost can be measured before
    changing a security-relevant KDF parameter.
2026-08-17 Add Bitwarden import, optimize perf/memory, rebrand to IndraOps
    Bitwarden import (Settings -> Import -> Bitwarden):
    - Streaming multipart file upload over the existing WiFi portal
    (restricted route set, own "import mode"), fed into a new
    hand-rolled streaming JSON parser (bw_json_parser.h/.cpp) scoped to
    the Bitwarden export schema, bounded memory regardless of input size
    - Two-stage pipeline (bw_import.ino): stage 1 streams+stages parsed
    records to a temp file with duplicate detection; stage 2 (explicit
    user confirm) builds a new encrypted vault, verifies it record-by-
    record, then atomically swaps it in -- a failed import never touches
    the existing vault
    - New screens: source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
    [06_PasswordManager.ino, bw_import.ino, db_migrate.ino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]
2026-08-17 Fix WiFi portal AP client cap starving the initial join
    WiFi.softAP() was called with max_connection=1 — the SoftAP accepted
    exactly one client association, ever. Phones (notably iOS) open a
    silent background probe connection for captive-portal detection before
    the connection the user sees completes; with only one slot available,
    that probe could occupy it and the real join would fail or hang, even
    at point-blank range (reported: stuck on the Bitwarden Import wait
    screen, unable to join SecureKey-Setup at all).
    Raise max_connection to 2. This does not loosen the portal's actual
    security boundary: every state-changing/data-revealing route still
    requires the single per-session 6-digit code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
    [wifi_portal.ino]
2026-08-17 Add WiFi portal diagnostics; raise weak TX power; fail loud on AP start
    The max_connection fix (fe9cecd) alone did not resolve "stuck on the
    Bitwarden Import WiFi wait screen" for a station that still can't join
    at all, even at point-blank range. Two more real issues, plus the
    instrumentation needed to tell them apart without guessing again:
    - WiFi.setTxPower() was WIFI_POWER_8_5dBm (~7 mW) — framed in the
    original comment purely as "cut a brownout-triggering current
    spike," but that's the second-weakest setting available and can be
    marginal for a reliable WPA2 handshake depending on hardware/
    enclosure. Raised to WIFI_POWER_13dBm (~20 mW) — still well below
    the documented bro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
    [06_PasswordManager.ino, wifi_portal.ino]
2026-08-17 Fix PIN unlock screen stomping its own success redraw
    onTapPin() unconditionally called drawPin() at the end of every tap
    path (BS, OK, and the auto-submit-on-last-digit path). pinTryUnlock()
    -> pinUnlockSuccess() already fully redraws the destination screen
    (SCR_HOME, or SCR_MIGRATE_V3 on a one-time DB upgrade) and fades it
    in on a correct PIN -- but that trailing drawPin() then immediately
    repainted the empty keypad right back over it. The vault WAS unlocked
    (current was genuinely SCR_HOME internally), but the screen always
    showed a fresh empty PIN pad, indistinguishable from the unlock having
    silently failed/reset -- 100% reproducible on every correct entry,
    with no red shake (correctly,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
    [screen_pin.ino]
2026-08-17 Fix Bitwarden Import button appearing dead on tap
    importWarnShow() (called when tapping "Bitwarden Import" on the
    Settings -> Import source-select screen) set importWarnPending=true
    and called drawAll() -- but `current` was still SCR_IMPORT_SOURCE at
    that point, and the ONLY place that checks importWarnPending is
    drawImportWait()'s body. So drawAll() just redrew the unchanged
    source-select list, which was visually indistinguishable from the tap
    doing nothing at all -- while the row above it ("General WiFi
    Manager", identical hit-box math, same y1/y2 pattern) worked fine,
    confirming this wasn't a touch/coordinate bug.
    Fix: importWarnShow() now pushNav(SCR_IMPORT_WAIT) so its
    importWarnPendin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
    [screen_import.ino]
2026-08-17 Skip the post-flash Improv Serial wait in the web installer
    esp-web-tools (index.html's <esp-web-install-button>) successfully
    flashes this firmware every time -- bootloader/partitions/app all
    write cleanly -- but the install dialog then hung on "Preparing
    installation" and threw an uncaught "Error fetching current state:
    TIMEOUT" from requestCurrentState(). This is esp-web-tools waiting
    (10s default) for an Improv Serial handshake after a fresh install,
    a protocol this firmware never implements (it's a plain Arduino
    sketch using Serial.println() for its own debug logging, not
    Improv) -- so the wait always timed out even though the flash itself
    had already succeeded.
    Set new_install_improv_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
2026-08-17 Fix Bitwarden import reboot-on-upload and gate the upload UI behind auth
    Two real bugs from physical testing.
    REBOOT ON UPLOAD (the serious one) -- root cause confirmed by direct
    source read, not guessed:
    WebServer::_parseForm() (Parsing.cpp, this project's pinned ESP32 core
    2.0.16) copies the entire multipart upload body ONE BYTE AT A TIME
    inside a single synchronous call, calling back into our upload
    handler only once per 1436-byte chunk. That whole per-request copy
    loop runs inside one call to handleClient() with no yield during an
    actively-flowing transfer -- the only delay() in the library's own
    loop fires solely when the socket has momentarily no data.
    This project's sdkconfig has C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
    [bw_import.ino, wifi_portal.ino]
2026-08-17 Instrument the post-100% Bitwarden import reboot (do not guess-fix)
    Physical retest of the previous watchdog fix (21c38f5) shows the crash
    moved: the device no longer resets mid-transfer, but now reboots
    immediately after the browser reports "Uploading 100%", before any
    records appear. Re-reading the code confirms the heavy commit work
    (bwImportCommit(), the actual build+verify+swap) does NOT run
    automatically after upload -- it only runs later, from an explicit
    on-device CONFIRM tap. What runs synchronously in this window
    (bwImportEnd(): flush/close two small staging files, check parser
    state, flip one flag) is architecturally lightweight -- nothing in it
    obviously explains a crash from sta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
    [bw_import.ino, wifi_portal.ino]
2026-08-17 Fix PANIC reset during Bitwarden upload: BLE re-enabling itself over the WiFi AP
    Root cause confirmed by a physical serial capture, not guessed:
    [WIFI] stopping BLE before AP (shared radio)
    ...
    [BLE] resume advertising <- BEFORE the upload even started
    [BW-01] Upload started ...
    (silence -- device panics, port drops)
    wifiPortalStartCommon() deliberately calls hidBleEnd() before bringing
    up the SoftAP -- this hardware shares one 2.4 GHz radio between WiFi
    and BLE, and running both at once is a documented reset trigger here
    (see that function's existing "Restart-bug mitigation" comment). But
    the main loop()'s ~2 Hz BLE-management block had no awareness a WiFi
    portal sessio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
    [06_PasswordManager.ino]
